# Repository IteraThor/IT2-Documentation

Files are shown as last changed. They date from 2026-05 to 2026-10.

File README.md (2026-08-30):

# IT2 - Autodarts Scoring System Manual



> 🌍 **This manual is available in other languages:** [Deutsch](README.de.md) | [Nederlands](README.nl.md)  
> 🛠️ **Optional Upgrade:** Looking for the mounting plate? [View the IT2 Baseplate Manual](BASEPLATE.md)
> ---
> *Note: Since I'm managing this project on my own, I use AI to help with the repetitive parts of the documentation - mostly for managing hyperlinks and fine-tuning the wording. I'm currently focused on getting all the technical content out there so you can start building as soon as possible. I'll be doing a full proofread and "ironing out" the phrasing later, but if you spot anything confusing in the meantime, please let me know on Discord!*

Welcome to the official manual for the IT2 Autodarts Scoring System. This guide will walk you through the assembly process.

> 📥 **Download Files:** [IT2 System on Makerworld](https://makerworld.com/en/models/1334165)

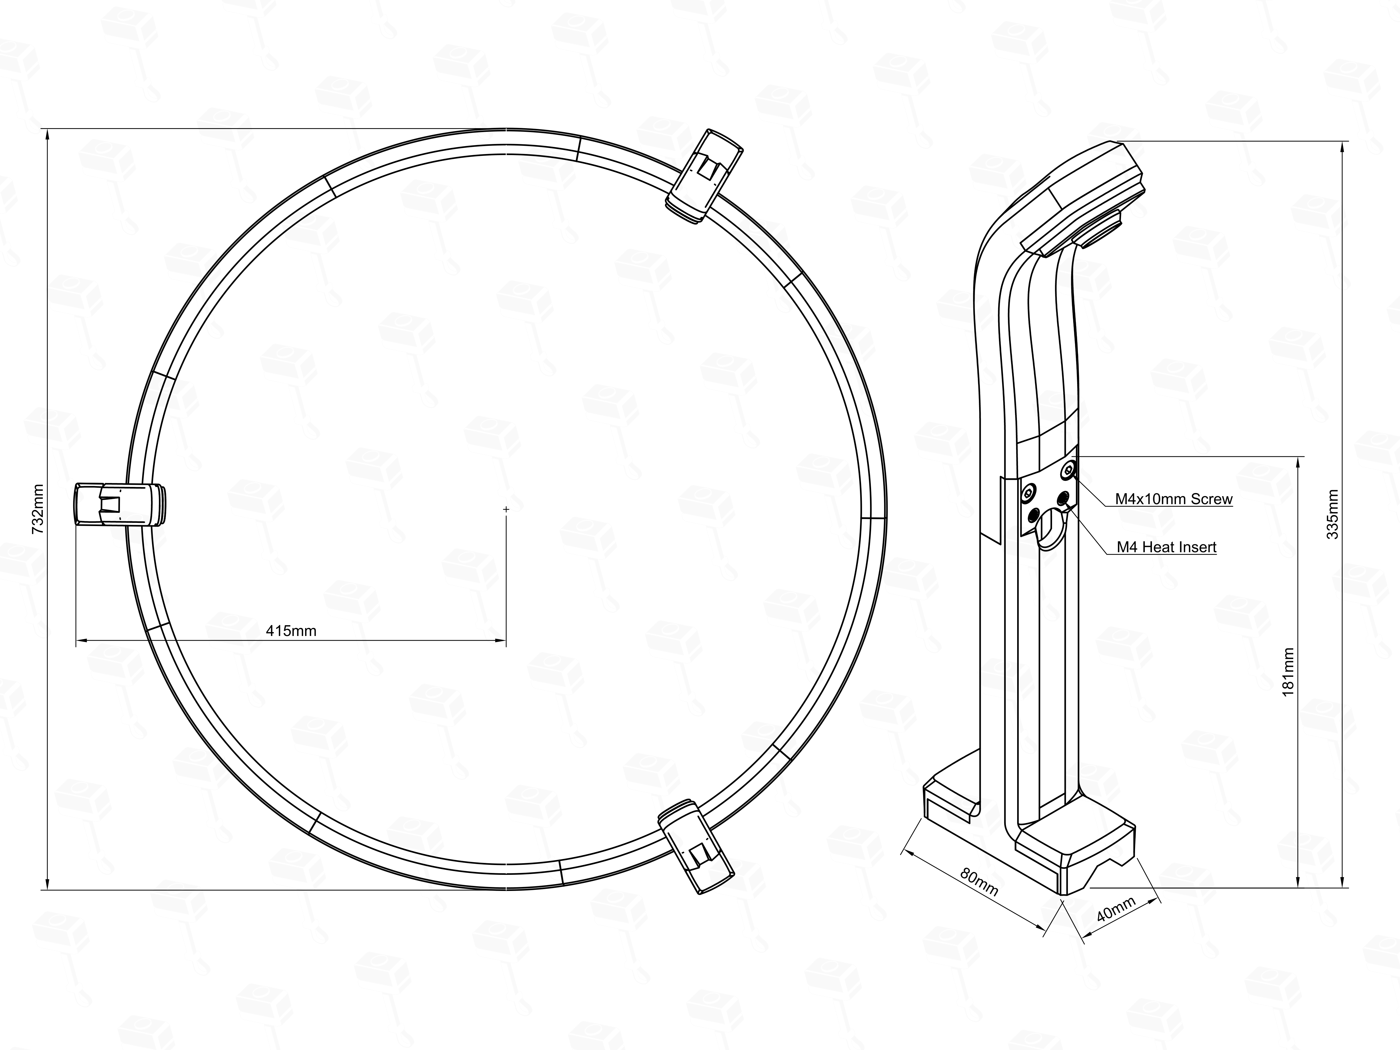
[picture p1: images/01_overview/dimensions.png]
dimensions


---
## Table of Contents
1. [General Overview](#1-general-overview)
2. [What You'll Need](#2-what-youll-need)
    * [2.1 Core Hardware (Required)](#21-core-hardware-required)
    * [2.2 Required Tools](#22-required-tools)
3. [General Assembly: Camera Arms](#3-general-assembly-camera-arms)
    * [3.1 Step 1: Camera Preparation & Resizing](#31-step-1-camera-preparation--resizing)
    * [3.2 Step 2: Heat Inserts Preparation](#32-step-2-heat-inserts-preparation)
    * [3.3 Step 3: Camera Installation & Closing](#33-step-3-camera-installation--closing)
4. [Build Options: Choose Your Path](#4-build-options-choose-your-path)
    * [4.1 Option 1: Winmau Plasma Light Ring](#41-option-1-winmau-plasma-light-ring)
    * [4.2 Option 2: IT2 DIY Light Ring](#42-option-2-it2-diy-light-ring)
    * [4.3 Option 3: Target Corona Light Ring](#43-option-3-target-corona-light-ring)
    * [4.4 Option 4: IT2 DIY Low Ceiling Light Ring](#44-option-4-it2-diy-low-ceiling-light-ring)
5. [Pre-Installation: Camera Positioning](#5-pre-installation-camera-positioning)
6. [Final Step: Installation & Wall Mounting](#6-final-step-installation--wall-mounting)
    * [6.1 Mounting Instructions: Direct Wall Mounting (Option A)](#61-mounting-instructions-direct-wall-mounting-option-a)
    * [6.2 Mounting Instructions: Baseplate Mounting (Option B)](#62-mounting-instructions-baseplate-mounting-option-b)
7. [Pro Tips & Troubleshooting](#7-pro-tips--troubleshooting)
    * [7.1 Assembly Best Practices](#71-assembly-best-practices)
    * [7.2 Hiding Winmau Plasma Power Cable](#72-hiding-winmau-plasma-power-cable)
    * [7.3 Hiding Target Corona Power Cable](#73-hiding-target-corona-power-cable)
8. [Recommended Electronics](#8-recommended-electronics)
9. [FAQ](#9-faq)
10. [Licensing & Community Support](#10-licensing--community-support)

---

## 1. General Overview

### Key Features
*   **Sleek & Slim Design** - The slimmest 3D-printed LED Light Ring as of 2026.
*   **Hidden Cable Management** - Internal routing for a clean look. Fits Corona or Plasma power barrels without any modifications.
*   **No-Support Printing** - Designed for zero supports, minimizing material waste and print time.
*   **Universal Compatibility** - Native support for Winmau Plasma, Target Corona, and IT2 DIY Rings.
*   **Flexible Assembly** - Choose between the **Heat Insert** version or the **Self-Tapping** version (no heat inserts required).
*   **Minimalist Hardware** - Built using only 12x M4x10mm screws and 6x M2x6mm screws.

---

## 2. What You'll Need

> **Note:** Many of the product links below are affiliate links. If you use them to make a purchase, I may receive a small commission at no additional cost to you, which helps support the development of this project.

> 🖨️ **3D Printing:** If you are not using the Makerworld .3mf profiles, please refer to the **[Universal Printing Guide](PRINTING.md)** for recommended settings and materials.

### 2.1 Core Hardware (Required) 

| Part Name | Type | Qty | Link | Comment |
| --- | --- | --- | ---- | --- |
| Cylindrical Screws | M4x10mm (ISO4762/DIN912) | 12  | [Aliexpress](https://s.click.aliexpress.com/e/_c4WUfT79)<br>[Amazon.de](https://amzn.to/49r8kCE) | Required for most of the assembly. |
| Cylindrical Screws | M2x6mm (ISO4762/DIN912)  | 6 | [Aliexpress](https://s.click.aliexpress.com/e/_c4WUfT79)<br>[Amazon.de](https://amzn.to/4u4l5du) | Camera screws. |
| M4 Heat Inserts ⚠️ | 6.3mm OD (max 9mm long) | 12  | [Aliexpress](https://s.click.aliexpress.com/e/_c3iaYfkD)<br>[Amazon.de](https://amzn.to/4wZr2uZ) | 6mm OD also fits. <br><br>⚠️ **Only for the Heat Insert version.** |

> 💡 **Looking for more?** [View Recommendations for Electronics & Accessories](#8-recommended-electronics)

### 2.2 Required Tools

| Tool | Link | Purpose |
| --- | --- | --- |
| Hex Key Set | [Aliexpress](https://s.click.aliexpress.com/e/_c3OuwTrf)<br>[Amazon.de](https://amzn.to/4nWmdhU) | For M4 and M2 cylindrical screws. |
| Pliers / Side Cutters | [Aliexpress](https://s.click.aliexpress.com/e/_c4NYxuoH)<br>[Amazon.de](https://amzn.to/3PBMeql) | Required for resizing the camera frames from 38x38 to 32x32. |
| Soldering Iron | [Aliexpress](https://s.click.aliexpress.com/e/_c3Jtjkzn)<br>[Amazon.de](https://amzn.to/3PBMeql) | Required for melting M4 heat inserts (Heat Insert version only). |

---

## 3. General Assembly: Camera Arms

Before building your specific version (DIY, Winmau Plasma, or Target Corona), you need to prepare and assemble the three camera arms. This process is identical for all versions.

### 3.1 Step 1: Camera Preparation & Resizing
> Some cameras come with a 38x38mm mounting frame. To make them fit, you need to **break the outer frame** to downsize them to **32x32mm**.

*   Carefully break off the perforated edges using a pair of pliers.

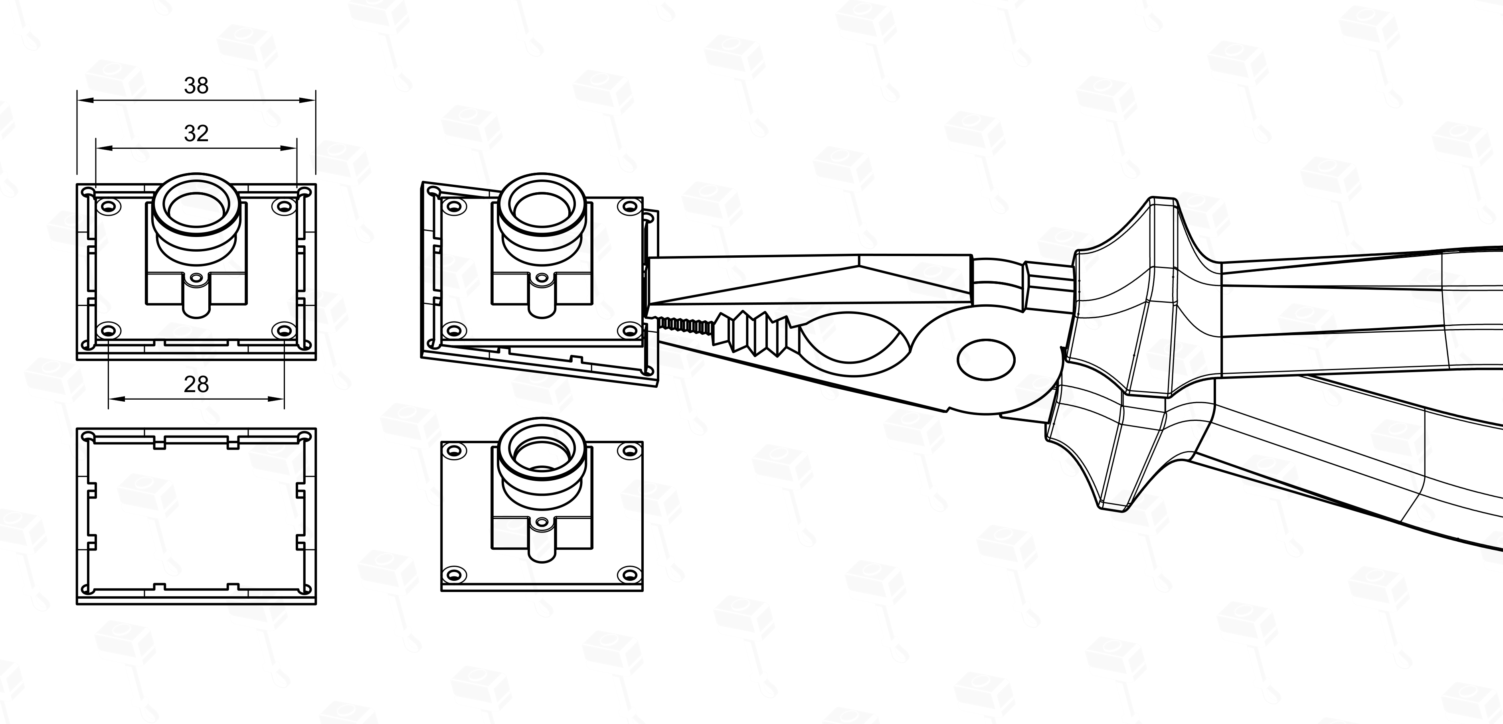
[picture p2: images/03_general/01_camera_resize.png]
camera-resize


### 3.2 Step 2: Heat Inserts Preparation
> **Self-Tapping Version:** If you printed this version, you can skip this step.

Melt the **M4 inserts** into the holes of the camera arms and heads using a soldering iron, as shown in the image below.

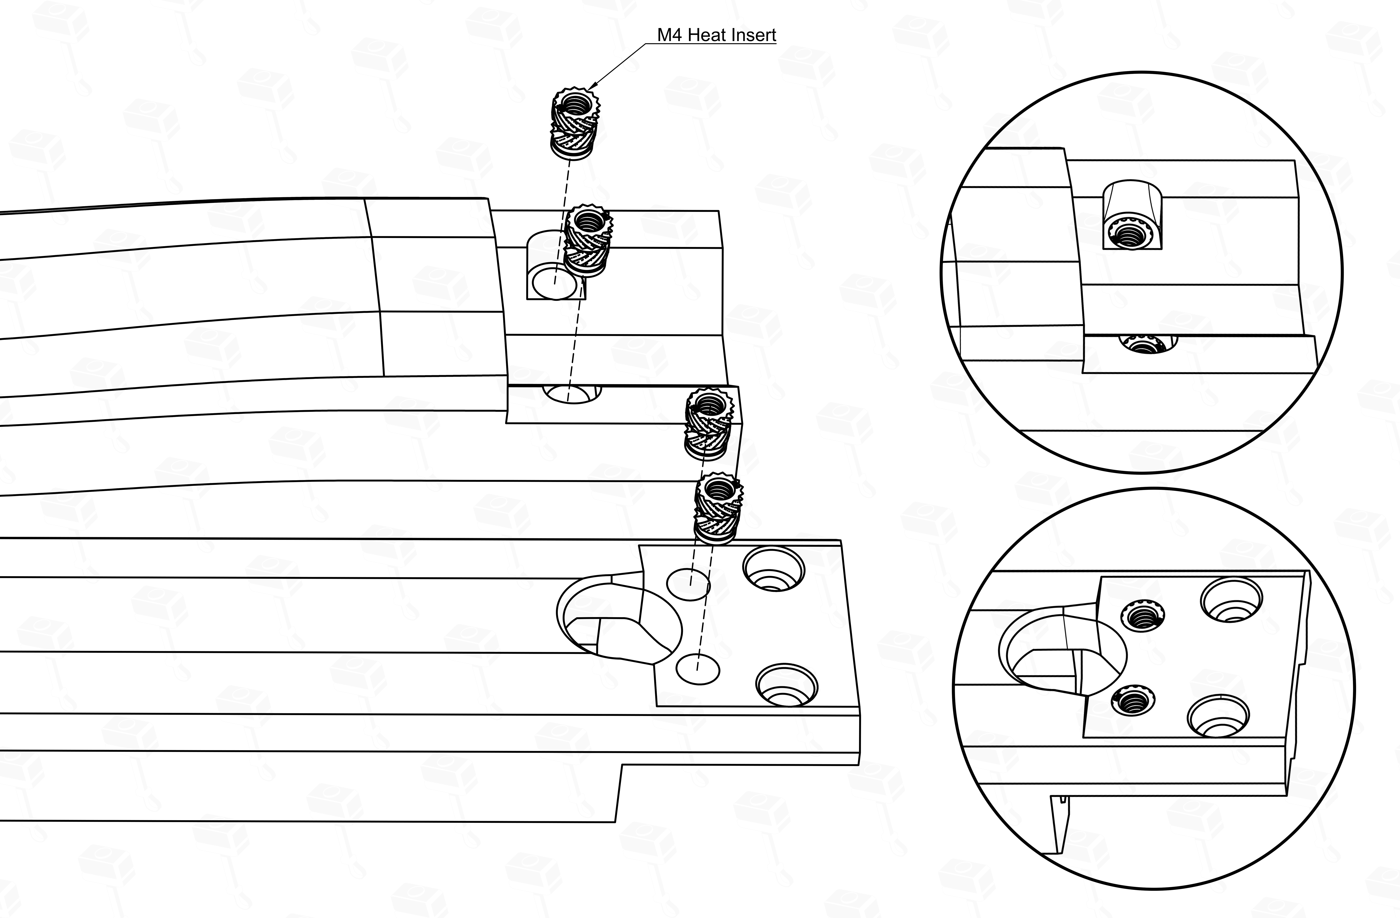
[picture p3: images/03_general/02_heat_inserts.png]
heat_inserts


### 3.3 Step 3: Camera Installation & Closing
**1. Head & Arm Assembly**  
Connect the camera head and the arm using two **M4 screws**. After that, pull the USB cable through the internal channel of the housing and connect it to the 4-pin connector of the camera.

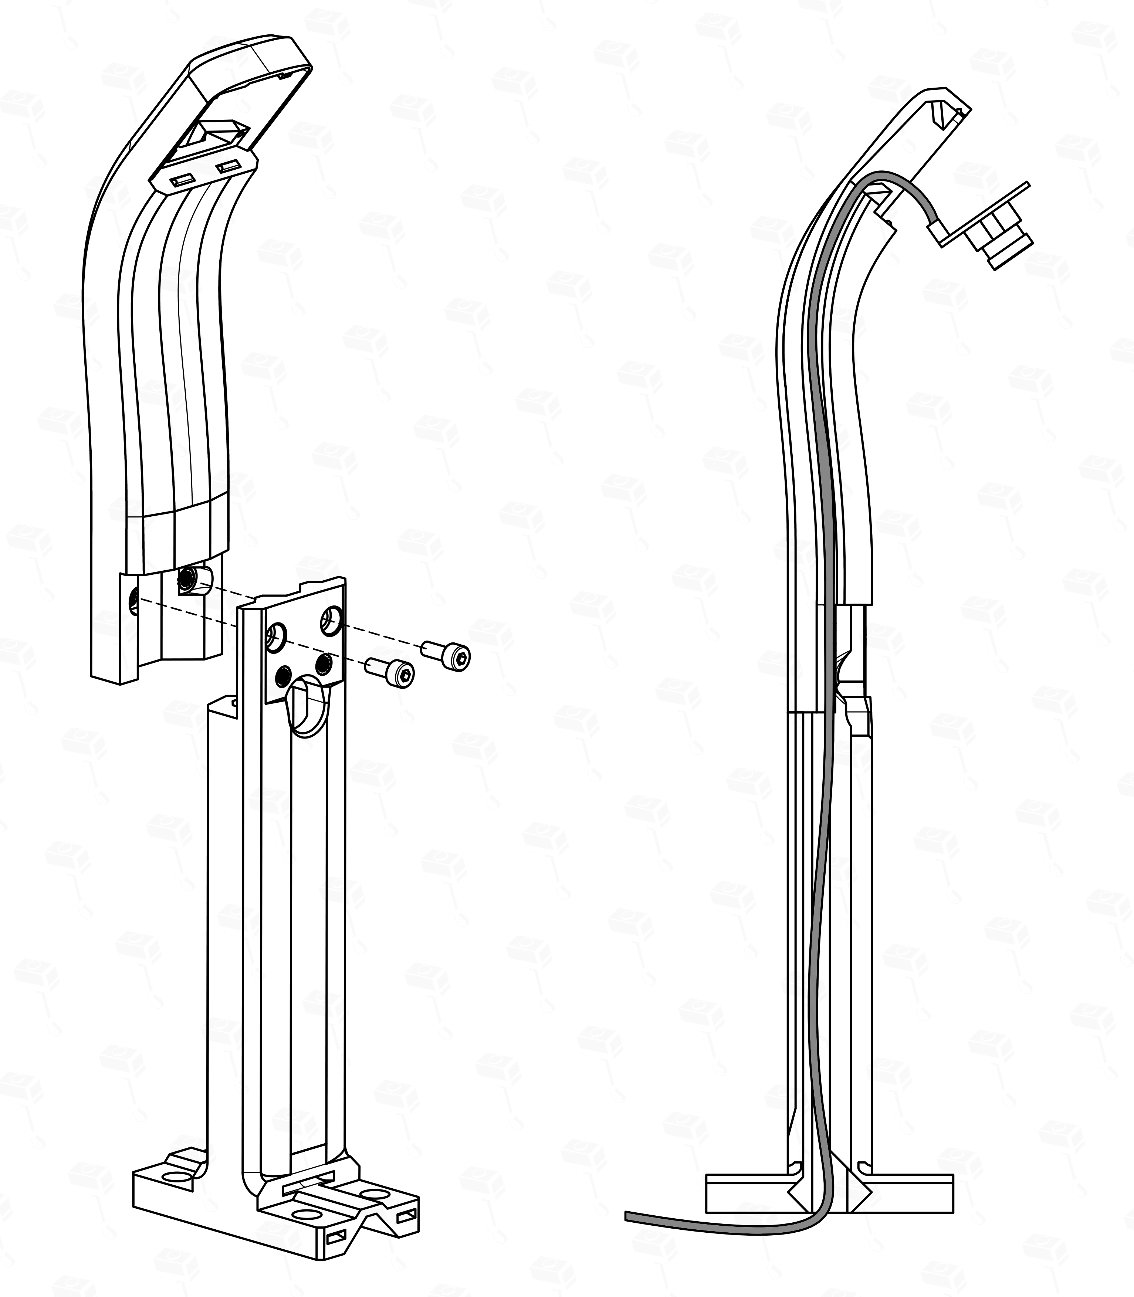
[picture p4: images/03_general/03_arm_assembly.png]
arm_assembly


**2. Camera Installation**  
Secure the camera PCB with two **M2 screws**. 

> **Note:** These holes are self-tapping. Using only two screws is recommended and intentional.

**3. Lens Hood & Closing**  
Twist the lens hood clockwise into the camera cover (twist-lock) and then click the cover onto the head.
> **Tip:** Choose between the two different lens hood designs included in the print profile.

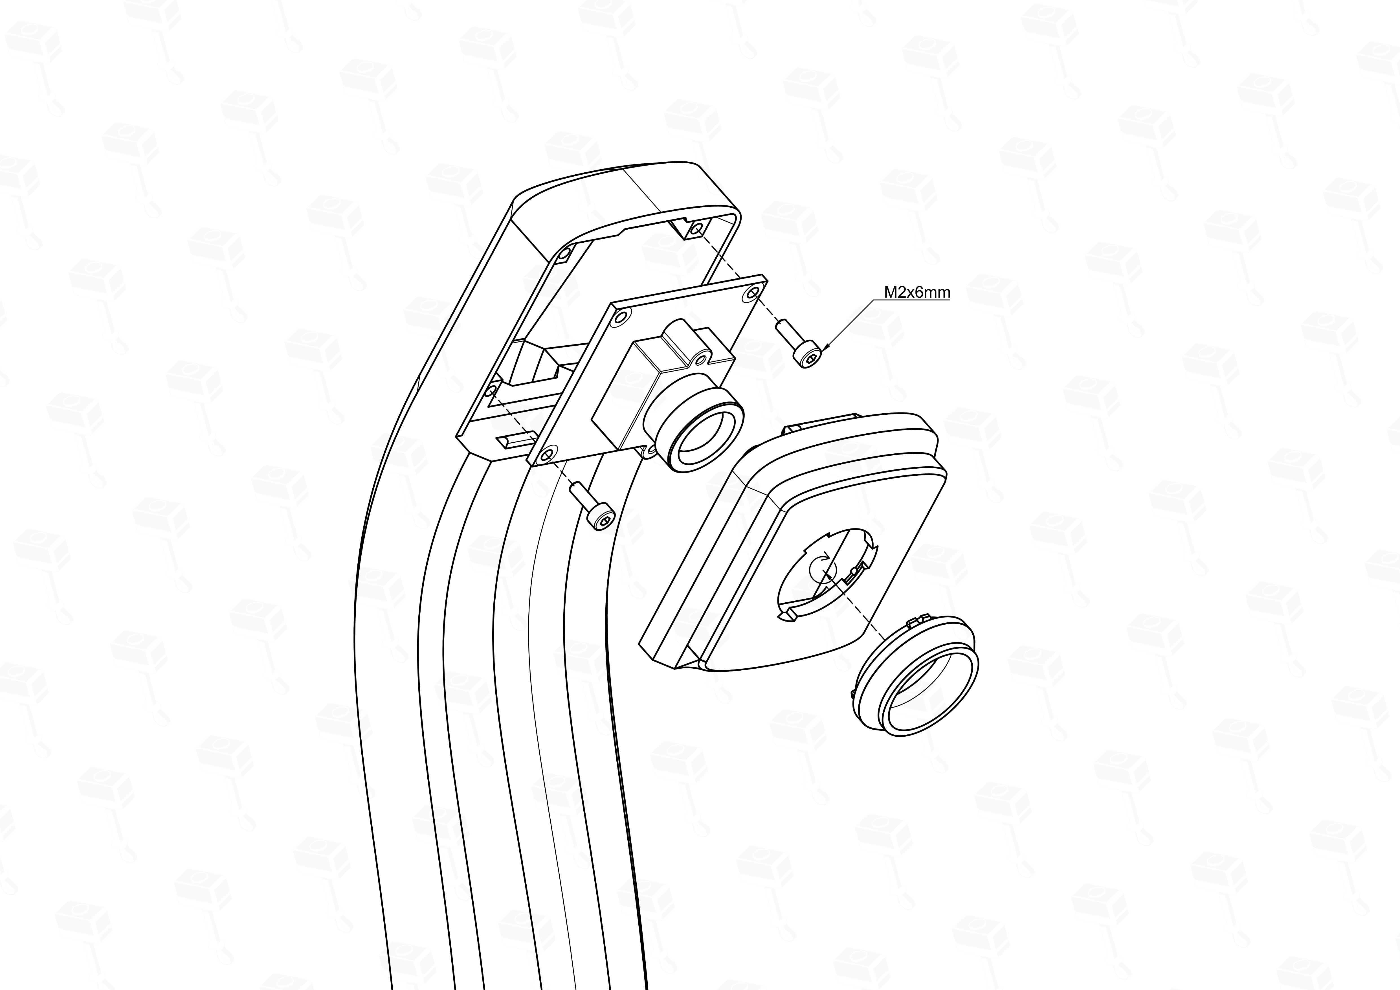
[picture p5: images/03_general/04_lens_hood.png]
lens_hood


**Final Result of Phase 1**  
Upon completing these steps, you should have three fully assembled camera arms ready for installation.

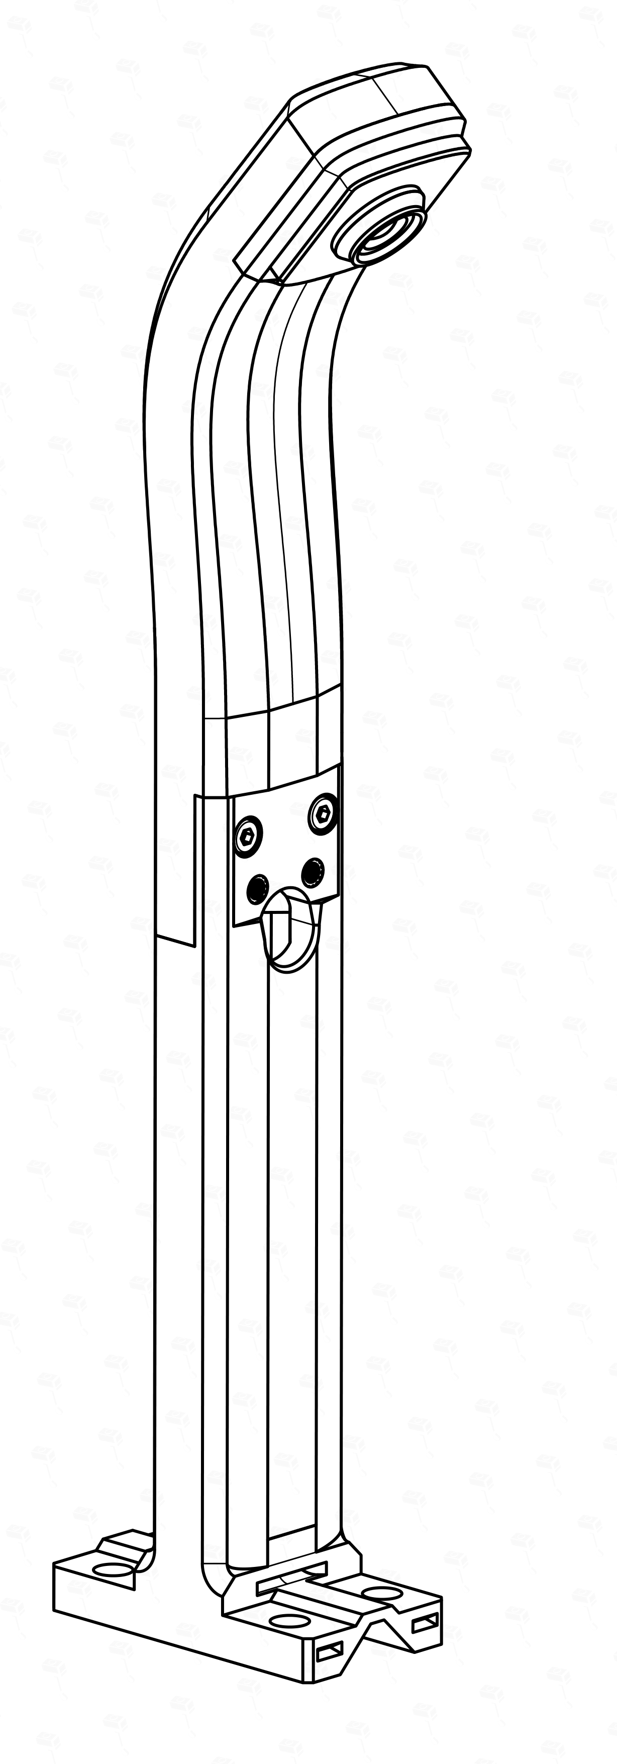
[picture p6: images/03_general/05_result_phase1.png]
fully assembled camera arms
[](images/03_general/05_result_phase1.png)

---

## 4. Build Options: Choose Your Path

After your camera arms are prepared, choose the build guide that matches your setup.

### 4.1 Option 1: Winmau Plasma Light Ring

> **Pro Tip:** You have the option to route the Winmau Plasma power cable through the internal channels of the IT2 system for an even cleaner look. This requires a few extra steps - see [Section 7.2: Hiding Winmau Plasma Power Cable](#72-hiding-winmau-plasma-power-cable) for details.

**Step 1: Mounting the Arms**  
Attach the three [prepared camera arms](#3-general-assembly-camera-arms) to the designated positions on the Winmau Plasma ring. The IT2 arms are designed to fit perfectly onto the Plasma's profile. Use M4 screws to secure them.  

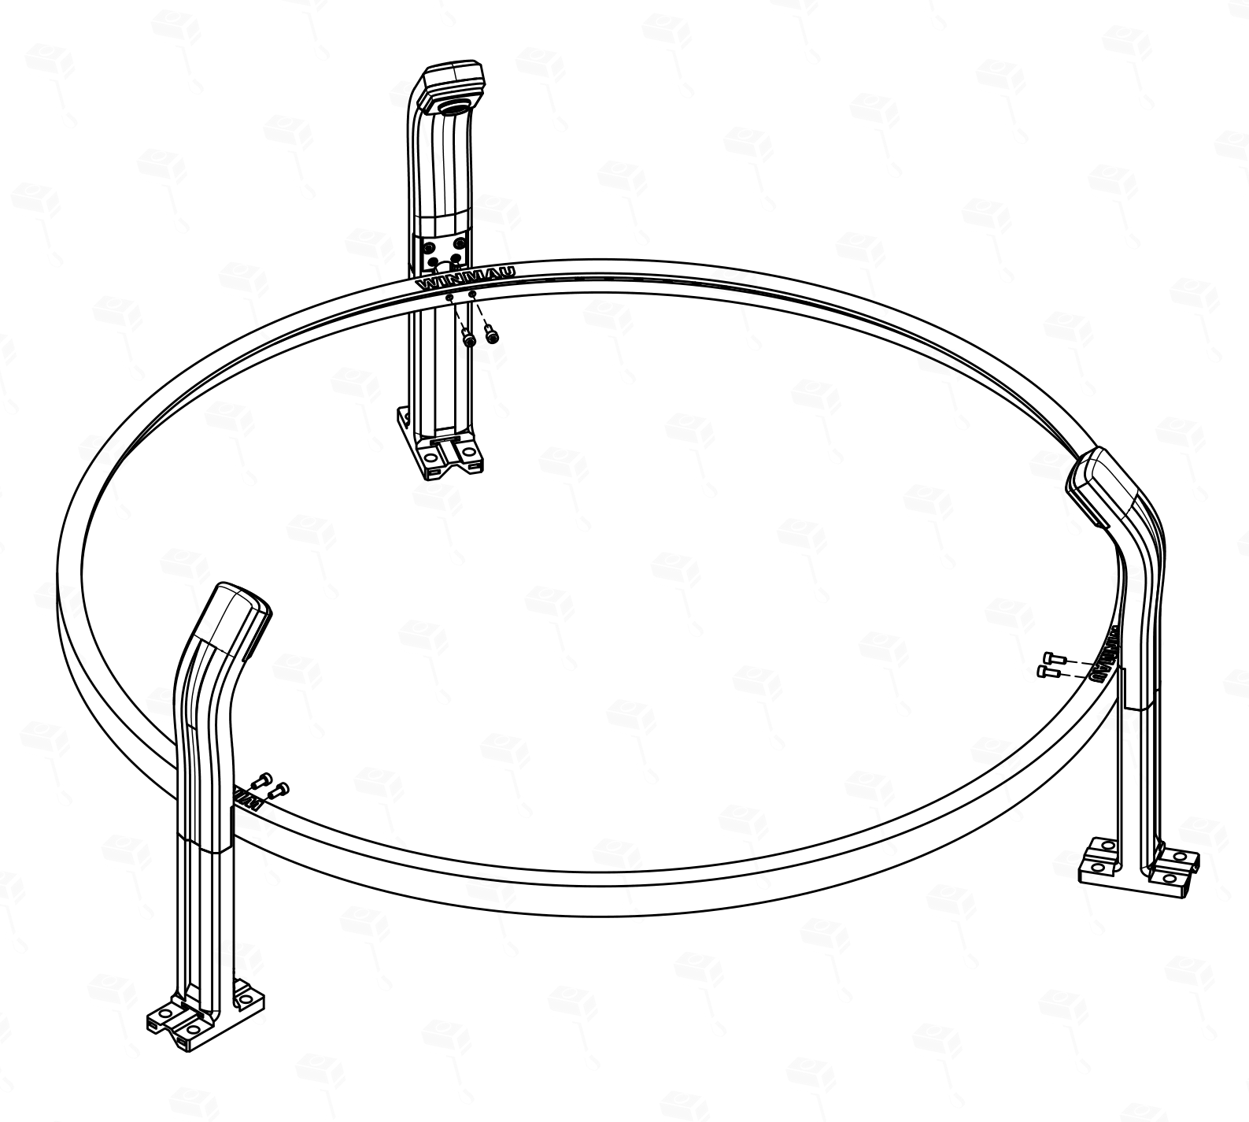
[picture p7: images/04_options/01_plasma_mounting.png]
plasma_mounting


[Back to Table of Contents](#table-of-contents) | **Next Step: [5. Pre-Installation: Camera Positioning](#5-pre-installation-camera-positioning)**

---

### 4.2 Option 2: IT2 DIY Light Ring

**Step 1: Ring Assembly**  
Connect the 3D-printed segments of the IT2 DIY Light Ring. Ensure a tight connection to maintain stability.

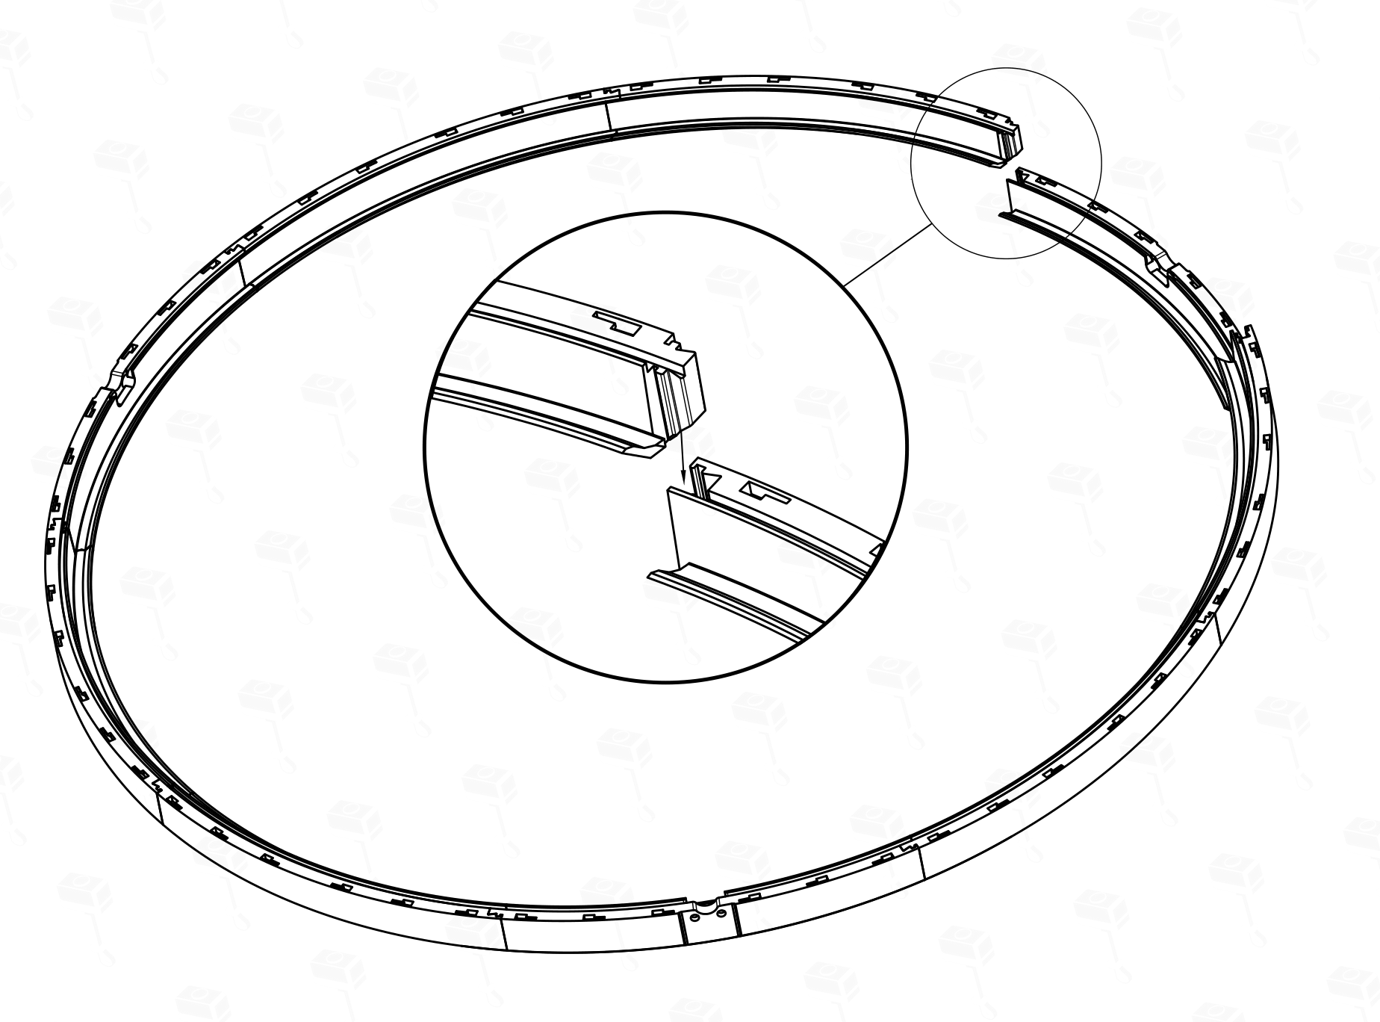
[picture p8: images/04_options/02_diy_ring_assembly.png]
ring_dovetail


**Step 2: LED Installation**  
Install the **LED strip** in the designated channel of the ring. Start from the bottom to allow for clean power cable routing.

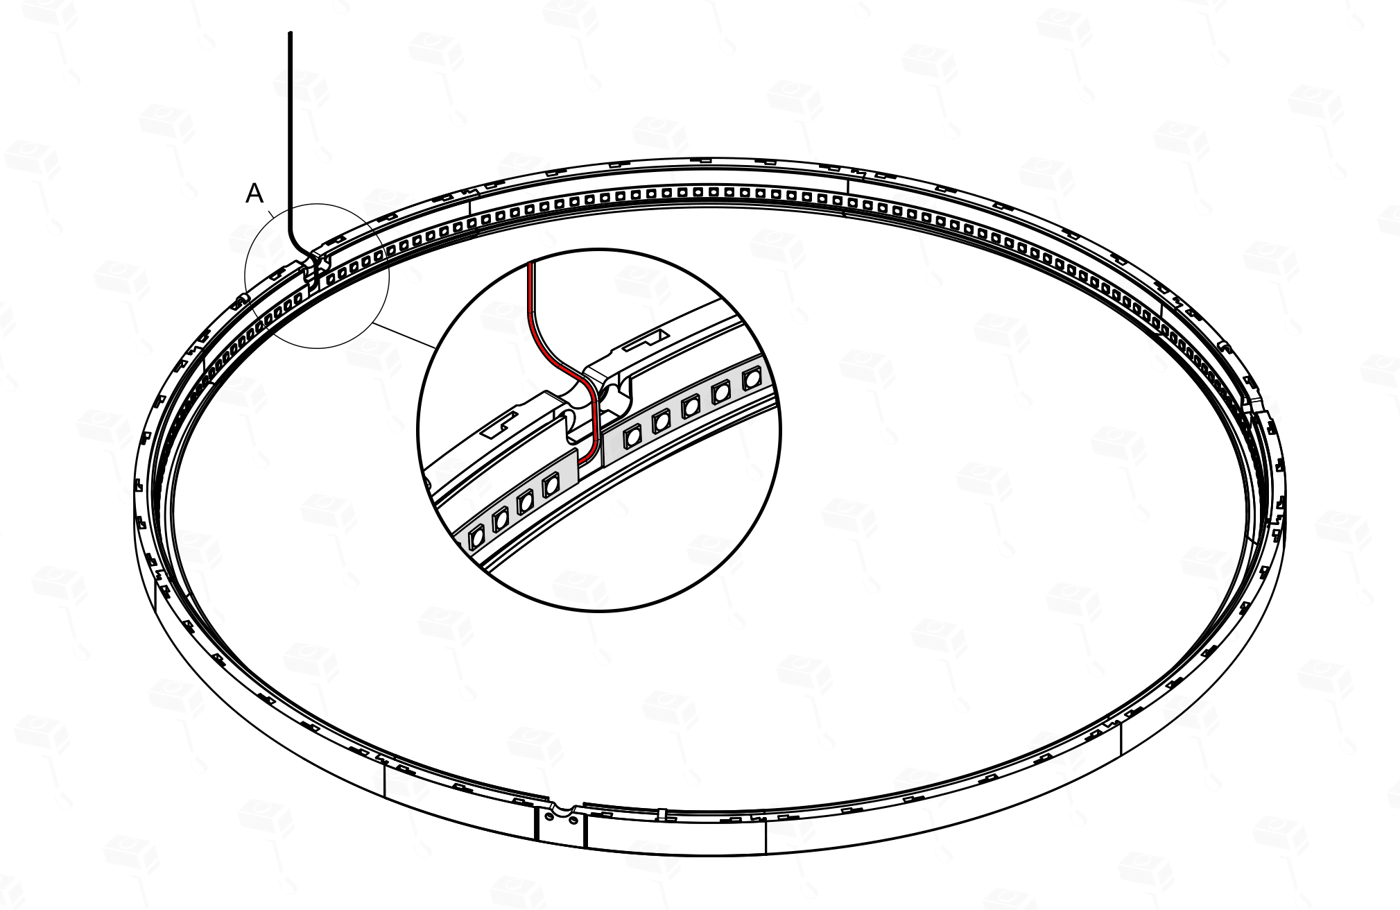
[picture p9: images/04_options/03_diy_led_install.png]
led_install


**Step 3: Attaching the Arms**  
Secure the camera arms to the integrated mounting points on the DIY ring using M4 screws.

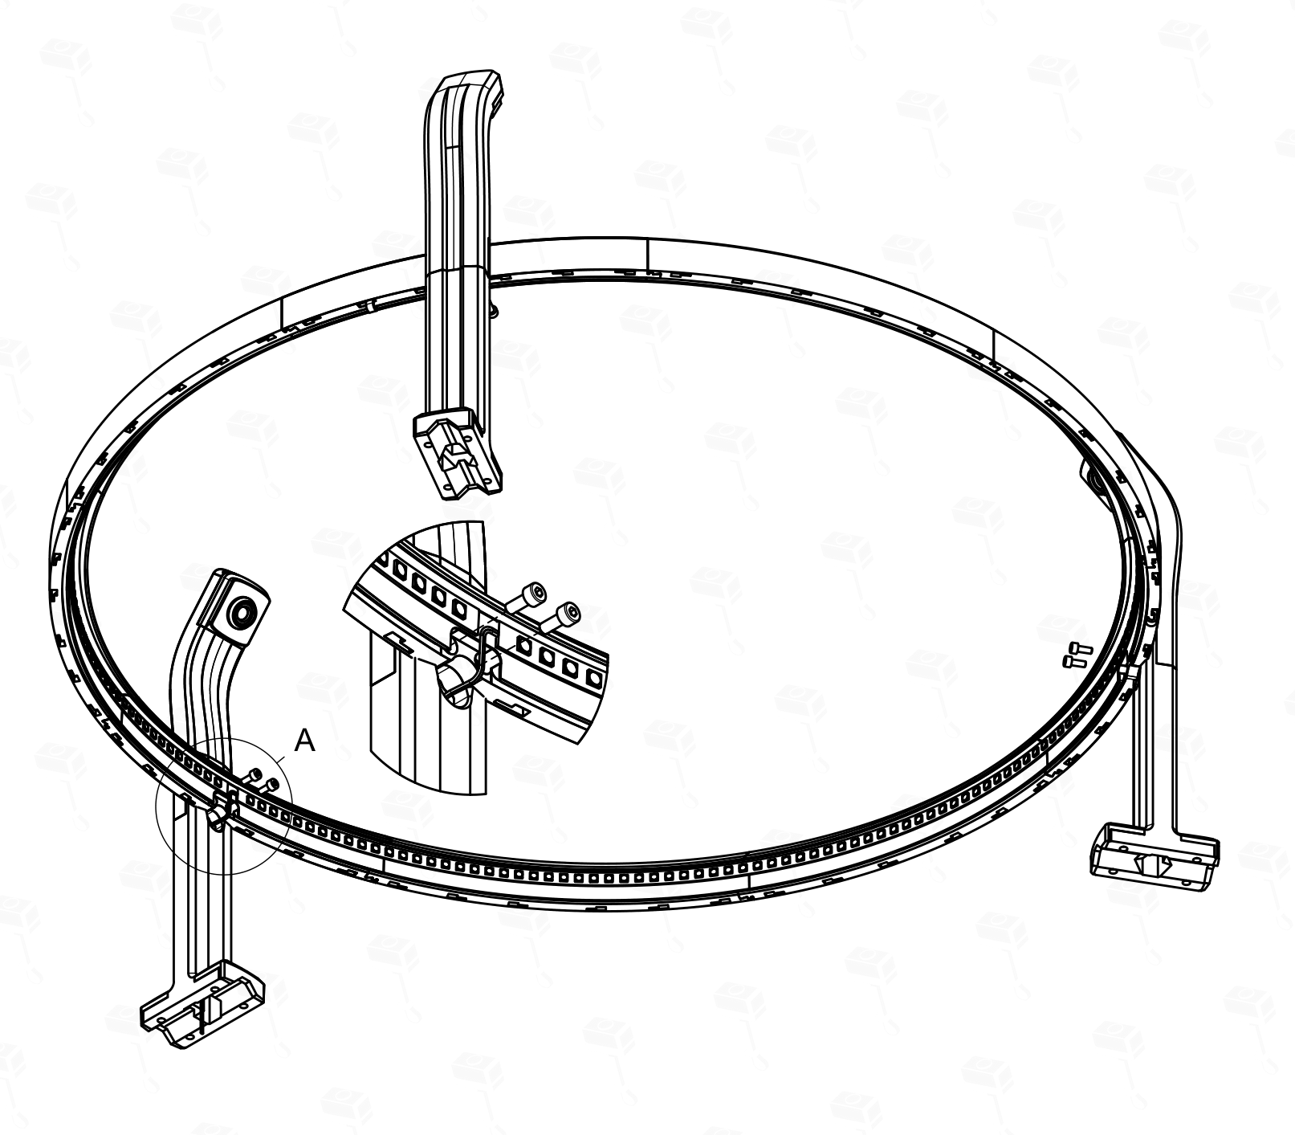
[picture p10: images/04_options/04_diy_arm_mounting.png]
arm_mounting


[Back to Table of Contents](#table-of-contents) | **Next Step: [5. Pre-Installation: Camera Positioning](#5-pre-installation-camera-positioning)**

---

### 4.3 Option 3: Target Corona Light Ring

**Step 1: Adapter Preparation**  
Install the **bottom part of the IT2 Corona Adapter** onto the three [prepared camera arms](#3-general-assembly-camera-arms) using M4 screws. 

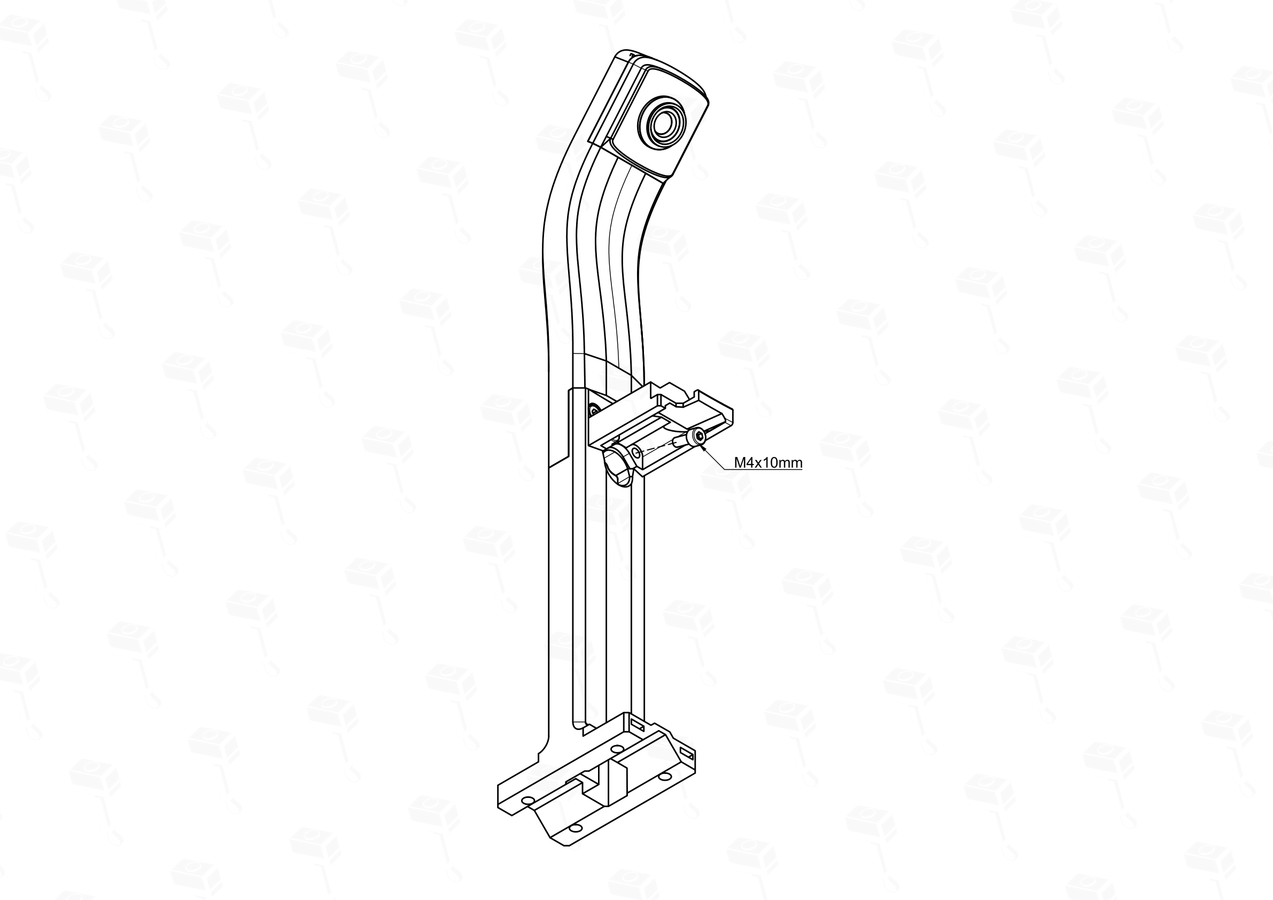
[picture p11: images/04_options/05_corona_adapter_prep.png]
corona_adapter_prep


**Step 2: Mounting & Alignment**  
Place the Target Corona ring into the recesses of the installed bottom adapter parts. 

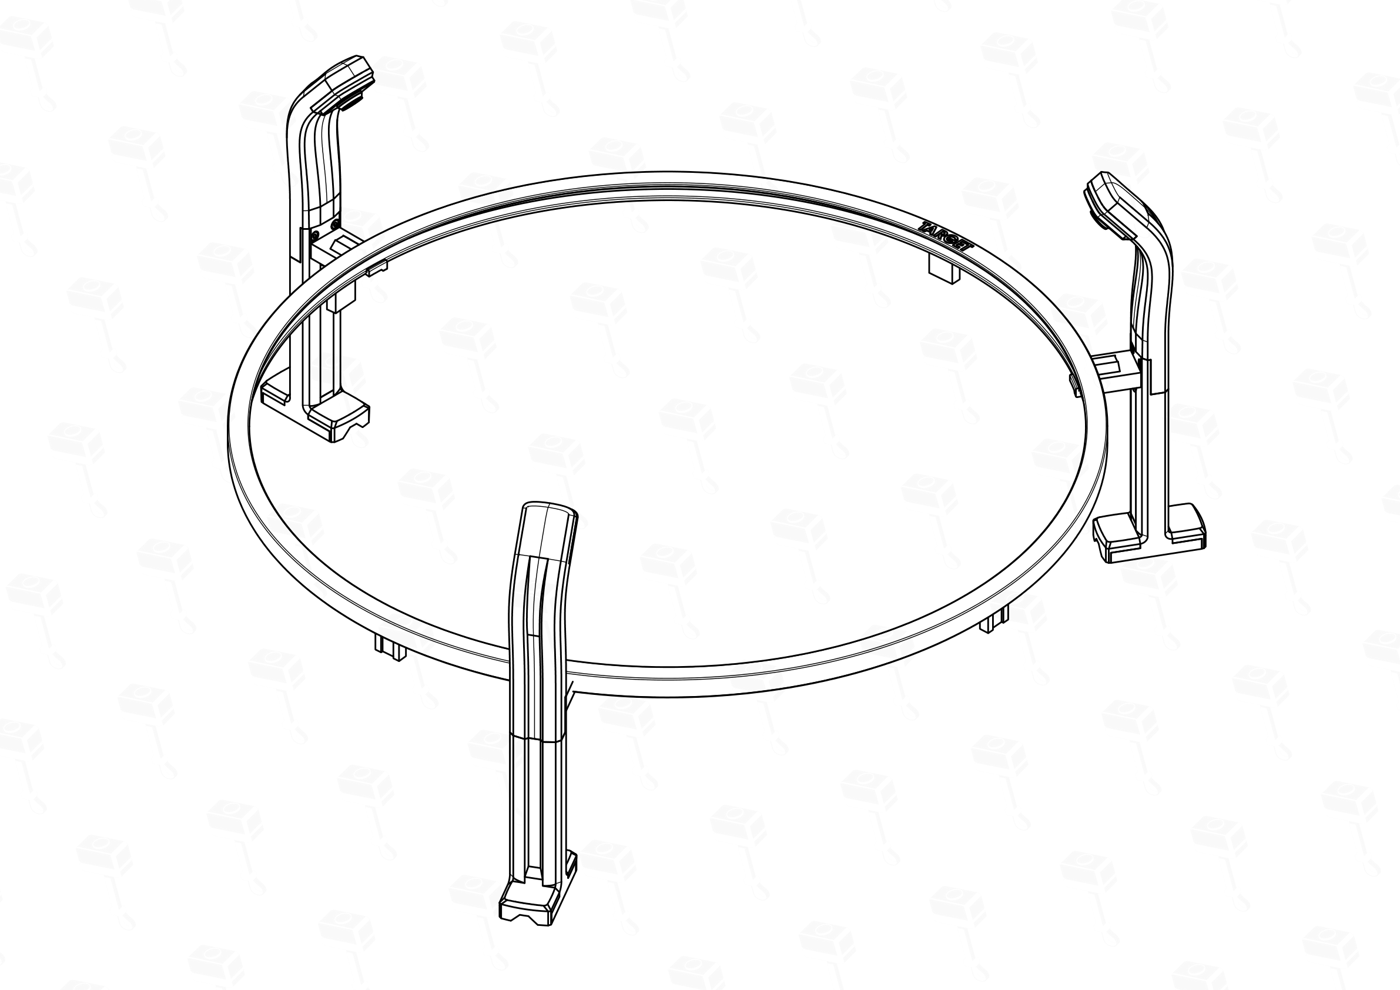
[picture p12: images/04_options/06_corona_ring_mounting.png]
corona_ring_mounting


Then, hook the **upper part of the adapter** into the ring and snap it into place. 

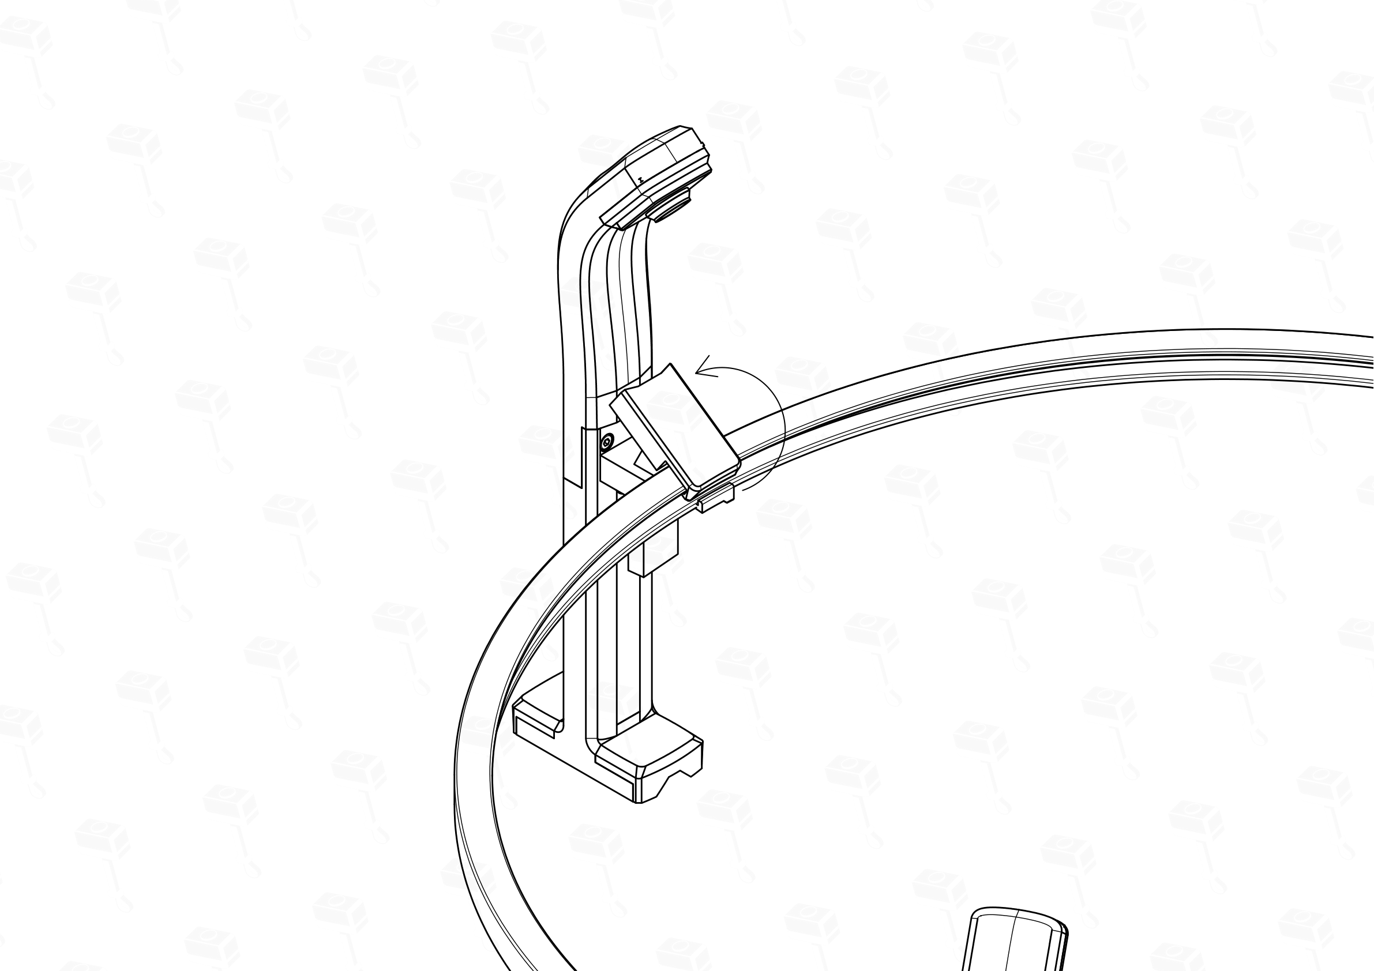
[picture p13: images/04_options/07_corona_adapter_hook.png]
corona_adapter_hook


> **Tip:** Try to position the adapters at an approximate **120-degree offset** while snapping them on. This will minimize the amount of fine-tuning needed later.

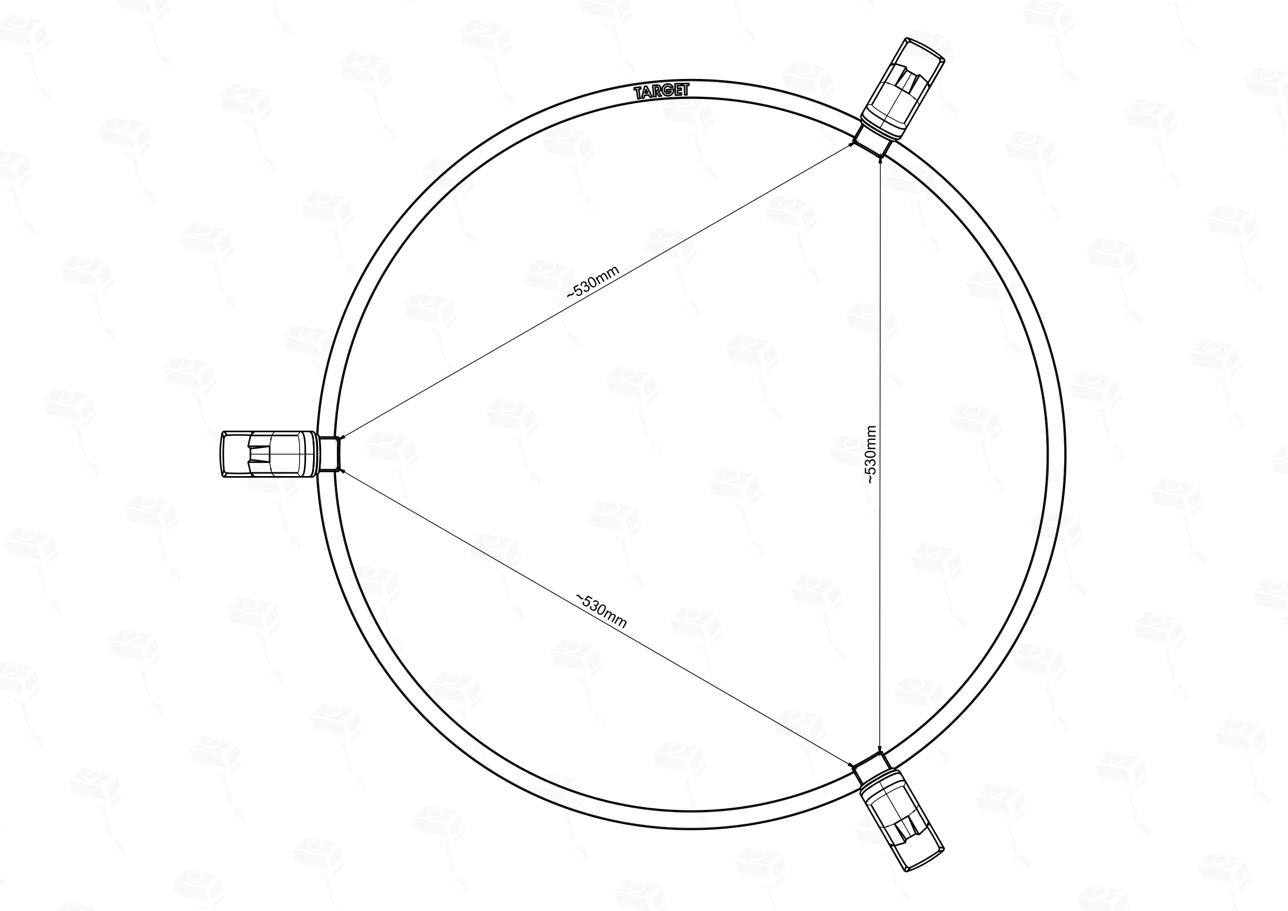
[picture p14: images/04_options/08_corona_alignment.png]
corona_alignment


> **Pro Tip:** You have the option to route the Target Corona power cable through the internal channels of the IT2 system for an even cleaner look. This requires a few extra steps - see [Section 7.3: Hiding Target Corona Power Cable](#73-hiding-target-corona-power-cable) for details.

[Back to Table of Contents](#table-of-contents) | **Next Step: [5. Pre-Installation: Camera Positioning](#5-pre-installation-camera-positioning)**

---

### 4.4 Option 4: IT2 DIY Low Ceiling Light Ring

> This version was specifically developed for rooms with low ceiling height. It requires a ceiling height of at least **2.00m**.

**Assembly Instructions**  
The assembly logic for this version is identical to the standard DIY ring. Please follow the detailed **[step-by-step instructions in Section 4.2](#42-option-2-it2-diy-light-ring)**.

> 💡 **Tip:** Unlike the standard ring, the Low Ceiling version consists of **6 different segment types**. Please note that all three segments that mount to the cameras are different from the standard version - two of them are mirrored and shorter to accommodate the ceiling clearance. Before connecting the dovetails, lay out all pieces on the floor in the correct order to avoid sequence errors. Once connected, the pieces are often very difficult to pull apart without risking damage.

**Final Result**  
After assembly, your Low Ceiling Light Ring should look as follows:

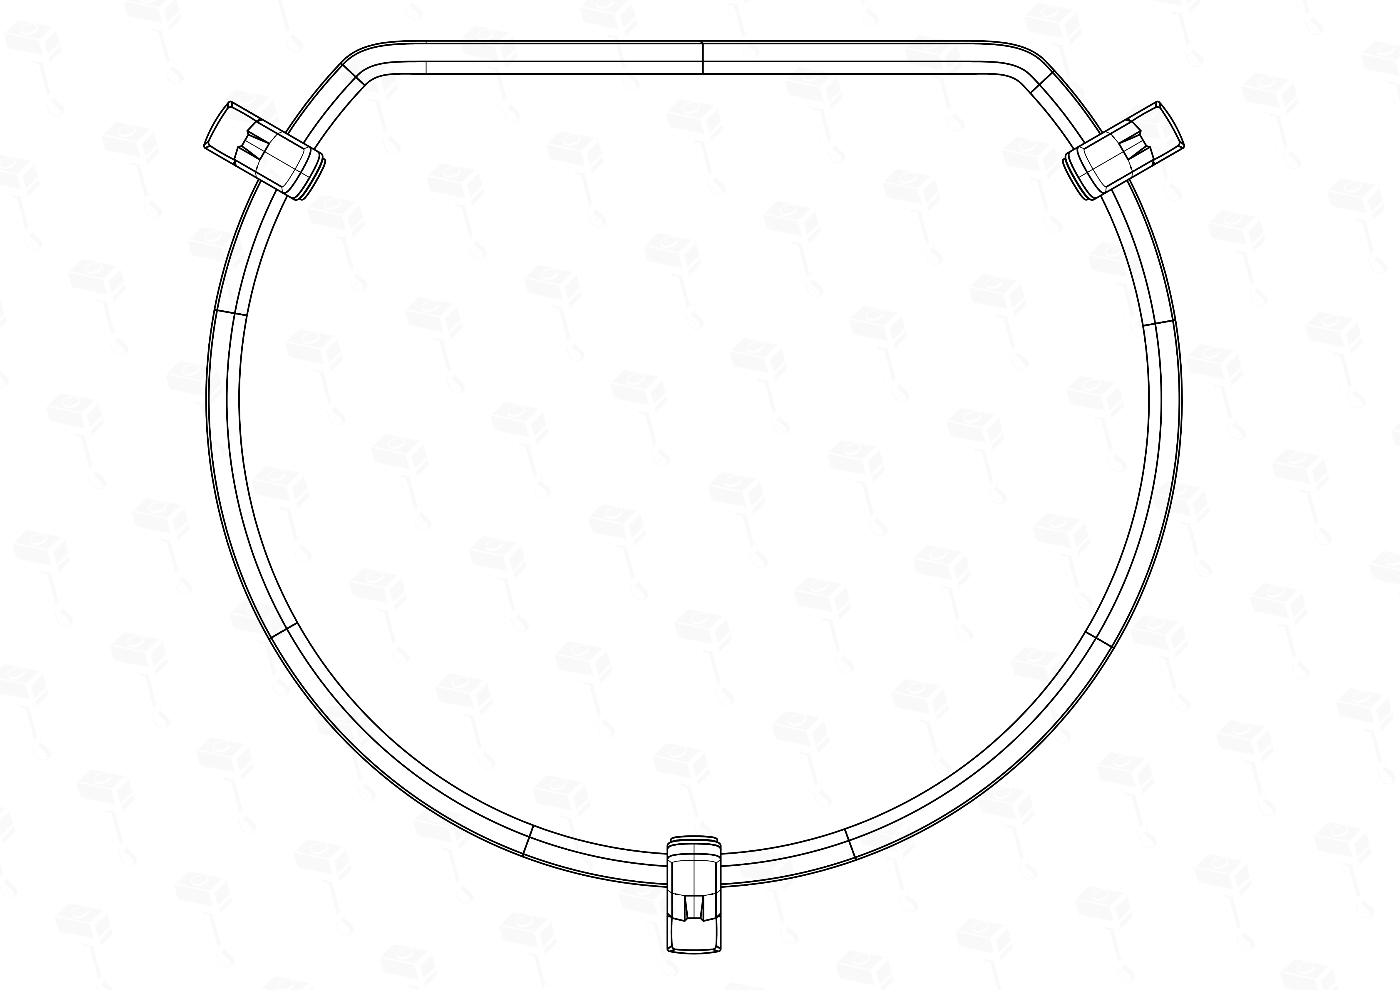
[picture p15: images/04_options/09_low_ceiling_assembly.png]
low_ceiling_assembly


[Back to Table of Contents](#table-of-contents) | **Next Step: [5. Pre-Installation: Camera Positioning](#5-pre-installation-camera-positioning)**

---

## 5. Pre-Installation: Camera Positioning

Before mounting your system, you need to decide on the orientation of your camera arms. 

> **Camera Positioning**  
> Align camera arms with the **11** or **6** segments for optimal recognition ([Autodarts Guidelines](https://autodarts.diy/getting-started/camera-positioning/)).  
> **Note:** The **Low Ceiling** or **portable stand** version uses the **3** segment instead.

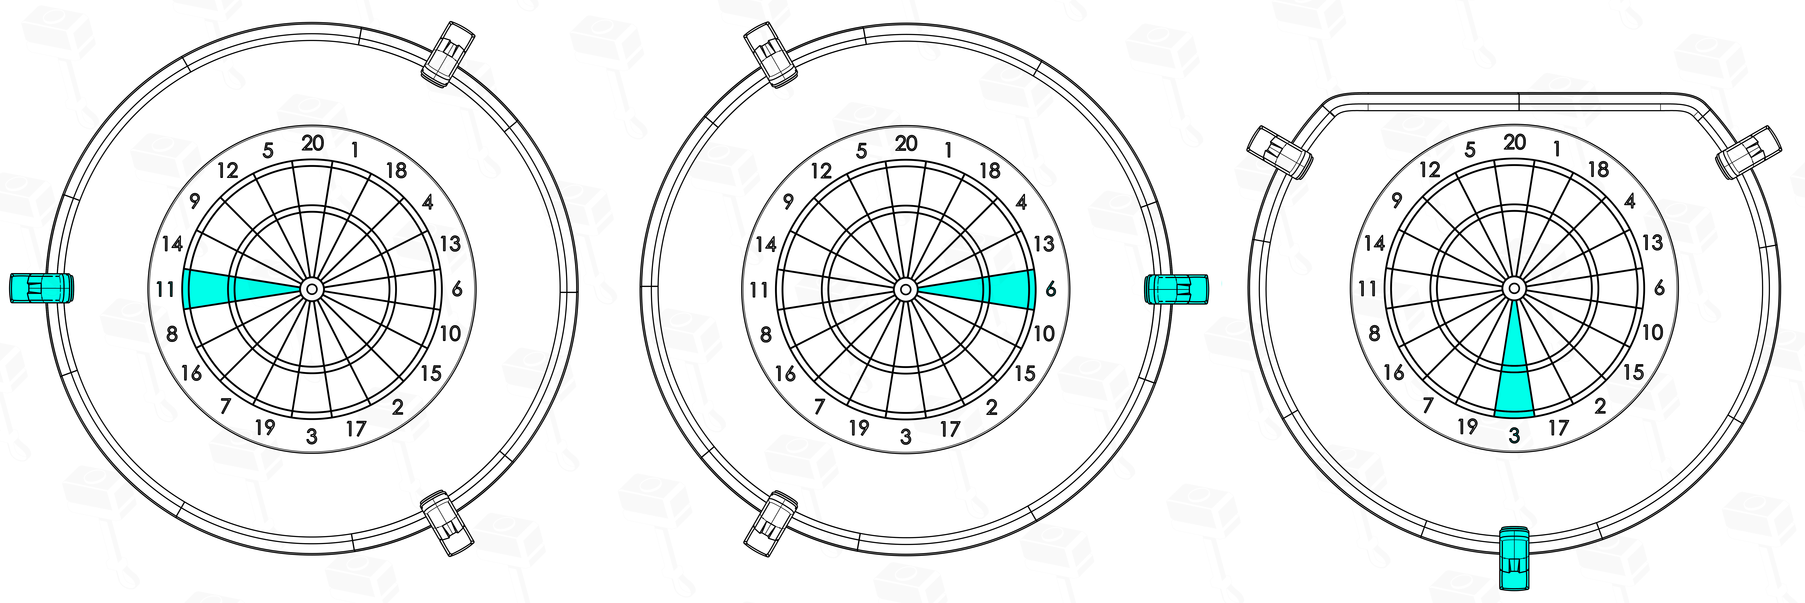
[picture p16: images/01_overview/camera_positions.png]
camera_positions


---

## 6. Final Step: Installation & Wall Mounting

The IT2 system offers two main installation paths, depending on your requirements for aesthetics, mounting effort, and wall protection.

### Option A: Direct Mounting
In this configuration, the IT2 system is mounted directly to the wall. This requires drilling **6 holes** for the arms and **2 additional holes** for the dartboard hanger (if not already present).
*   **Pros:** Fewer parts to assemble; minimal footprint; system sits flush against the wall.
*   **Cons:** Requires more drill points; leg positions must be determined manually via measurements, drawing circles, or using a drill template.

### Option B: IT2 Baseplate
The **[IT2 Baseplate](BASEPLATE.md)** is an optional unit that simplifies the installation process and offers additional features like sound dampening and native stand compatibility.

For detailed instructions on how to install and align the baseplate, please refer to the **[Baseplate Assembly & Installation Guide](BASEPLATE.md)**.

---

### 6.1 Mounting Instructions: Direct Wall Mounting (Option A)
There are two ways to ensure your system is perfectly aligned when mounting directly to the wall:

#### Method 1: Using the IT2 Drill Template (Recommended)
This is the easiest and most precise way to position your mounting holes.
1. Align the center of the template with your marked bullseye height (1.73m).
2. Level the template.
3. Mark the drill positions through the designated points on the template.
    > 💡 **Tip:** To minimize drilling while maintaining perfect stability, I recommend using only **two diagonal holes** per arm (e.g., top-left and bottom-right) instead of all four.

> 💡 **Tip:** If you want to change the orientation of the camera arms (e.g., placing the main arm on the left instead of the right), simply flip the template upside down. You can then use a spirit level on the bottom edge to align it perfectly.

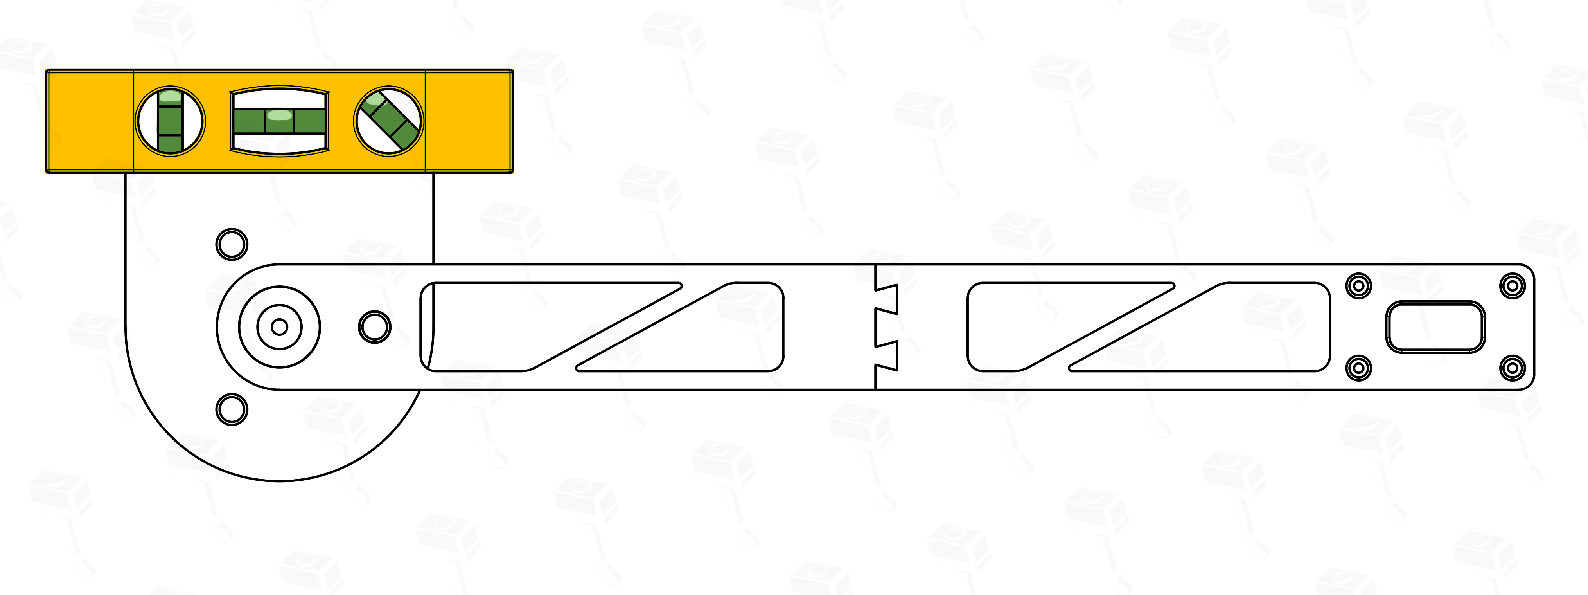
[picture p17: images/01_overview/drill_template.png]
drill_template


#### Method 2: Manual Marking & Drawing
If you prefer to mark the positions yourself without the 3D-printed template, follow the measurements shown in the technical drawing below. This ensures the correct 120-degree offset and distance from the bullseye.

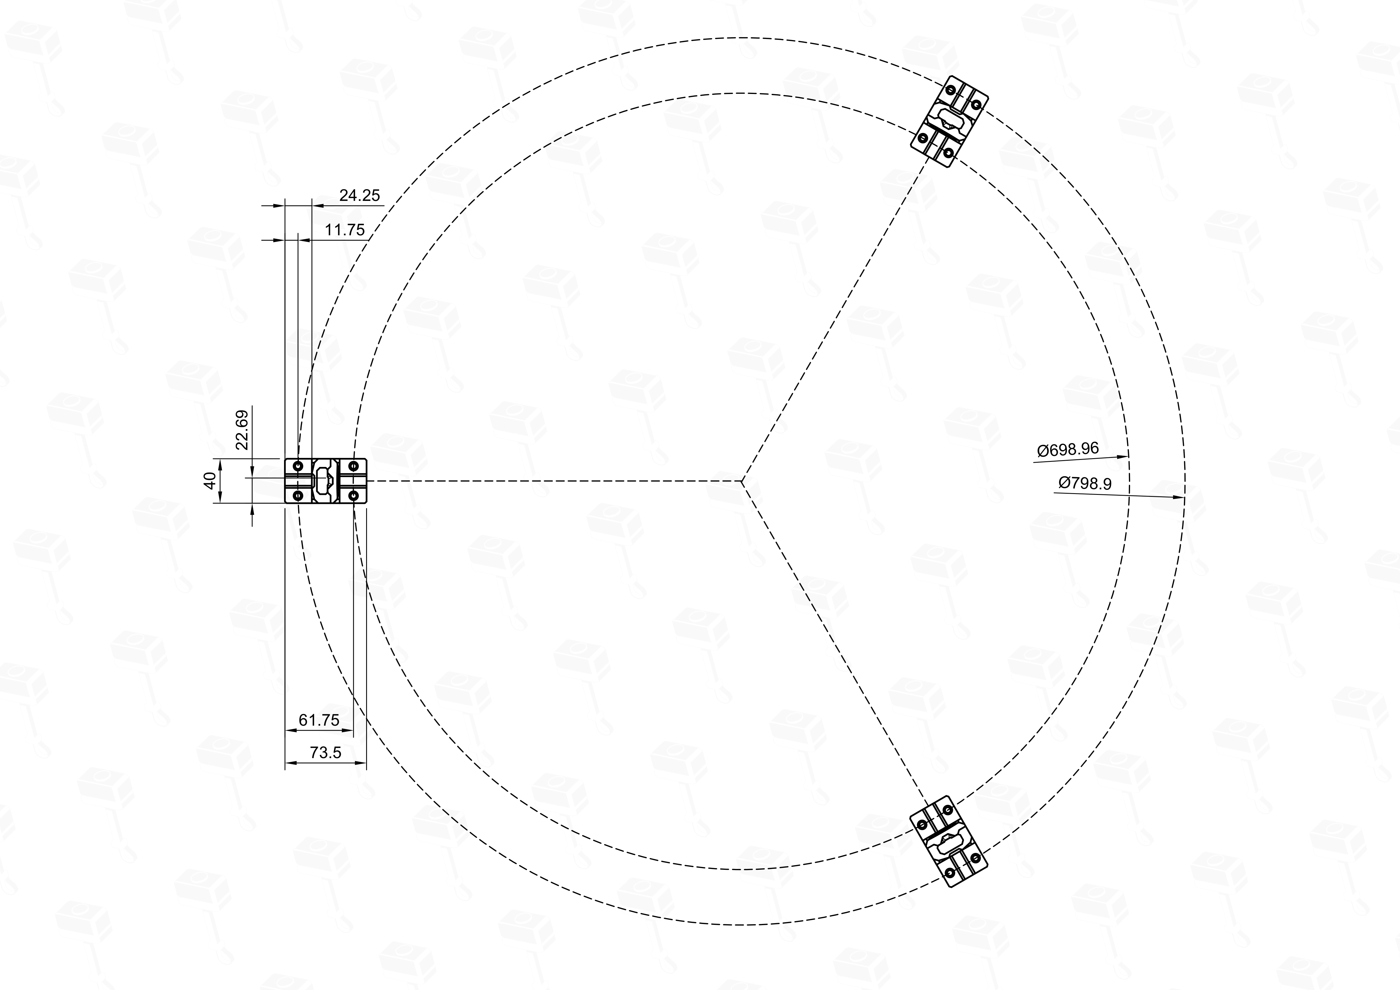
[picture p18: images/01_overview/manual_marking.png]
manual_marking


---

### 6.2 Mounting Instructions: Baseplate Mounting (Option B)
Please refer to the **[IT2 Baseplate Manual](BASEPLATE.md)** for detailed, step-by-step instructions on wall mounting and alignment.

[Back to Table of Contents](#table-of-contents)

---

## 7. Pro Tips & Troubleshooting

To ensure the best possible experience with your IT2 system, follow these pro tips.

### 7.1 Assembly Best Practices
When tightening screws, ensure they are only **"finger-tight"**.
*   Avoid over-tightening as this can stress the heat inserts.
*   **Self-Tapping Version:** Be extra careful with the self-tapping version. The plastic threads can easily strip, which is **irreversible** if too much force is applied.

### 7.2 Hiding Winmau Plasma Power Cable
**Step 1:** ...
**Step 2:** ...
*(Instructions coming soon)*

### 7.3 Hiding Target Corona Power Cable
**Step 1:** ...
**Step 2:** ...
*(Instructions coming soon)*

[Back to Table of Contents](#table-of-contents)

---

## 8. Recommended Electronics

| Part Name | Type | Link | Comment |
| --- | --- | ---- | --- |
| Cameras | HBV OV2710 | [Aliexpress](https://s.click.aliexpress.com/e/_c4bziy33) | Best price-to-performance cameras. |
| LED Strip | Auxmer 5000k 12V 9.6W LED Strip | [Aliexpress](https://s.click.aliexpress.com/e/_c3z7FC4l) | My favorite. Best color reproduction. |
| Power Supply | 12V 3A Power Adapter | [Aliexpress](https://s.click.aliexpress.com/e/_c2IYxq1R) | Required for the DIY LED strip. |
| DC Connector | 2.1mm DC Socket | [Aliexpress](https://s.click.aliexpress.com/e/_c3L2uy4H) | To connect the power supply to the LEDs. |
| PC | Dell Wyse 5070 ≥4GB RAM ≥ 16GB Storage | | My favorite. Good price-to-performance ratio. |
| Touchscreen  | Anmite 16" Touchscreen | [Aliexpress](https://s.click.aliexpress.com/e/_c34qKHYZ) | My favorite. Good price-to-performance ratio. |

---

## 9. FAQ

### Q: Which cameras should I choose?
**A:** The clear winner for price-to-performance is the **HBV OV2710**. Investing in more expensive, higher-resolution cameras is unnecessary as Autodarts is resolution-limited. While the **OV9732** is a cheaper alternative, it requires significantly better lighting; therefore, I exclusively recommend the OV2710 for its superior handling of various light conditions.

### Q: Which LED strip should I get?
**A:** Avoid USB light strips. The community favorite for a good, cheap strip is 6000K COB LEDs (12V or 24V). My personal recommendation is the Auxmer 5000K LEDs/m (9.6W, CRI90); in my tests, it even outperformed the Winmau Plasma. If you're on a budget, get a 6000K strip; if you want the best for your eyes and the cameras, get the Auxmer 5000K.

### Q: Should I use a Raspberry Pi or a Mini PC?
**A:** Unless you already own a Raspberry Pi, I recommend buying a refurbished Mini PC. They are often cheaper (starting at €50) and offer better performance and touchscreen support. My personal favorite is the **Dell Wyse 5070** (4GB RAM, 16GB storage), which is widely available refurbished and handles the Autodarts software perfectly.

---

## 10. Licensing & Community Support
IT2 is provided under a custom license. For information regarding commercial use, private sharing, and community support, please refer to the **[LICENSE.md](LICENSE.md)** file.

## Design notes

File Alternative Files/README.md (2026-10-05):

| File | Image  | Description |
| --- | --- | --- |
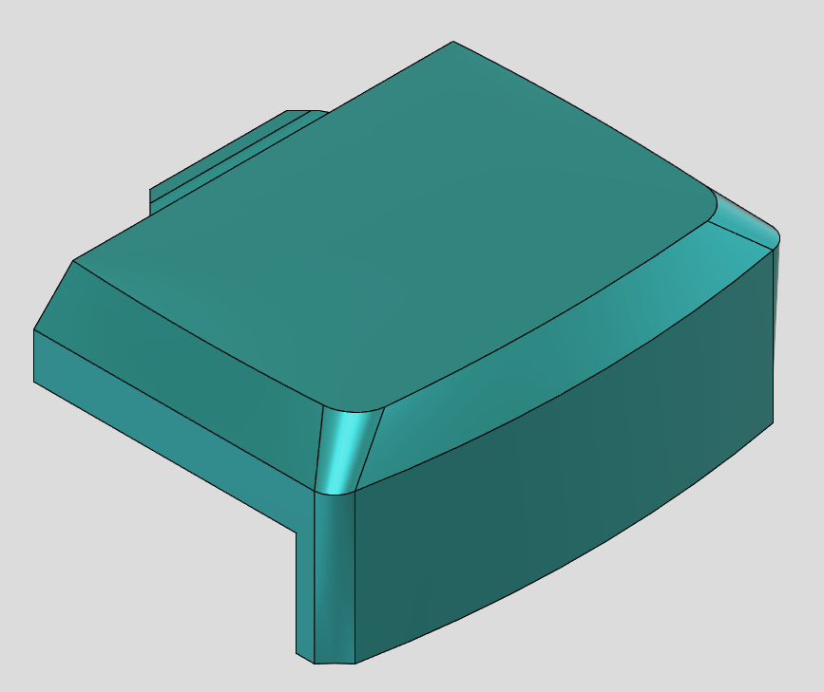
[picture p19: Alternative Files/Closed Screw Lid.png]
Closed Screw Lid
| closed screw lid.stl  |  | closed lid to close ends without cables. |

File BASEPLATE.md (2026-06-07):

# IT2 Baseplate - Installation & Assembly Guide



> 🛠️ **Main Manual:** Looking for the camera system instructions? [View the IT2 System Manual](README.md)
>
> ---
> *Note: Since I'm managing this project on my own, I use AI to help with the repetitive parts of the documentation - mostly for managing hyperlinks and fine-tuning the wording. I'm currently focused on getting all the technical content out there so you can start building as soon as possible. I'll be doing a full proofread and "ironing out" the phrasing later, but if you spot anything confusing in the meantime, please let me know on Discord!*

The **IT2 Baseplate** is a mounting solution for the IT2 Autodarts system. It is designed to simplify installation, protect your walls, and provide advanced features like sound dampening and native compatibility with dartboard stands.

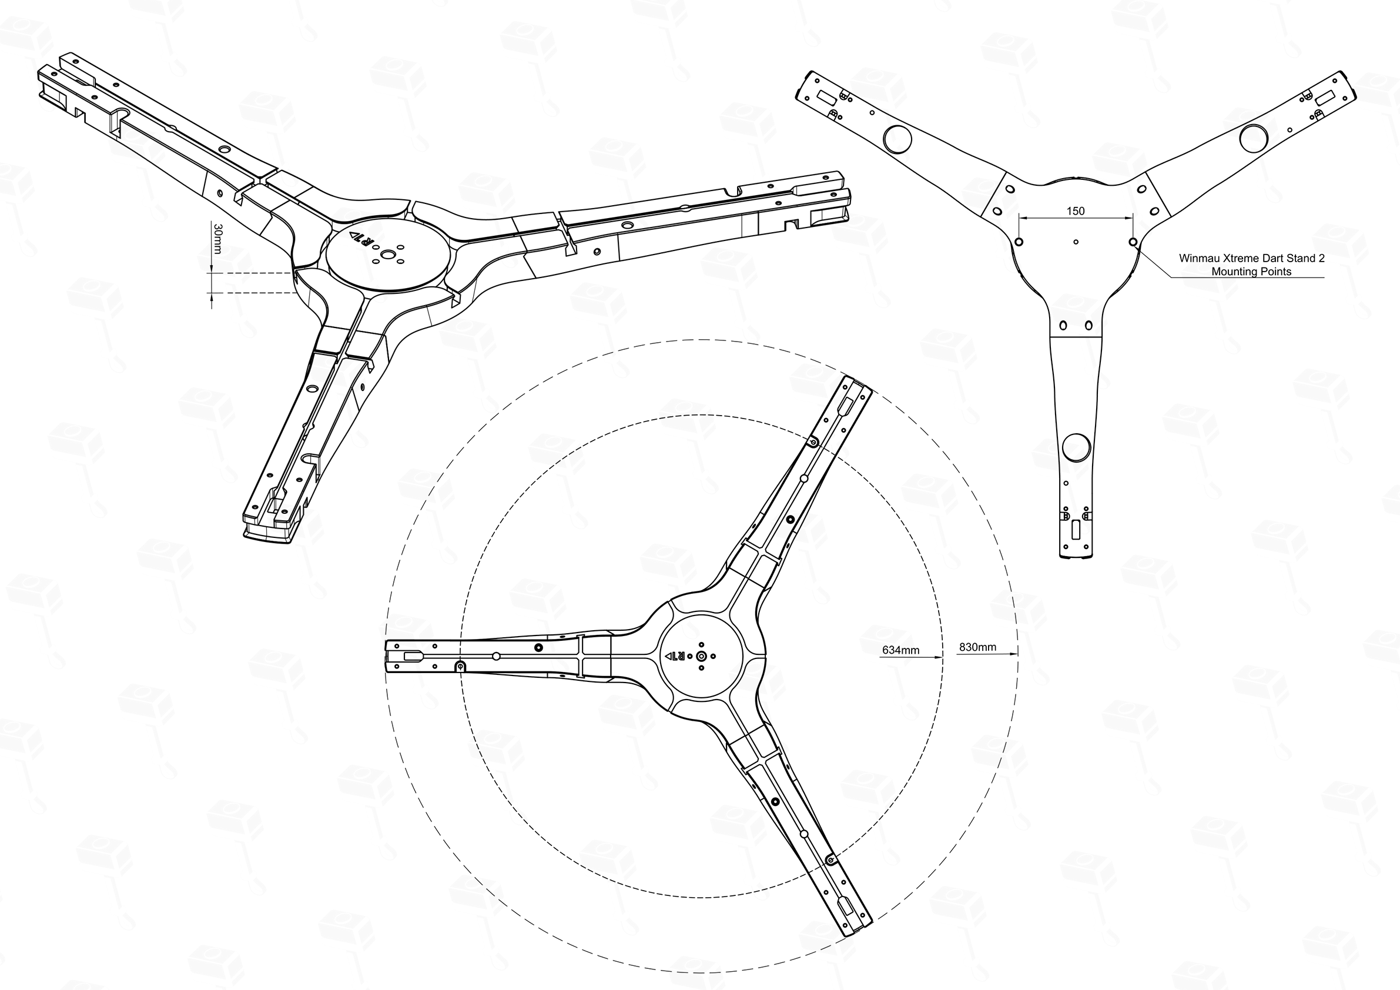
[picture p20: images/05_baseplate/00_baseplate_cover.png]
baseplate_cover


> 📥 **Download Files:** [IT2 Baseplate on Makerworld](https://makerworld.com/en/models/2782096)

---
## Table of Contents
1. [General Overview: The IT2 Baseplate](#1-general-overview-the-it2-baseplate)
2. [What You'll Need](#2-what-youll-need)
3. [General Assembly: Baseplate & System](#3-general-assembly-baseplate--system)
    * [3.1 Step 1: Installing Heat Inserts](#31-step-1-installing-heat-inserts)
    * [3.2 Step 2: Joining the Segments](#32-step-2-joining-the-segments)
    * [3.3 Step 3: Attaching the IT2 System](#33-step-3-attaching-the-it2-system)
4. [Final Step: Installation & Mounting](#4-final-step-installation--mounting)
    * [4.1 Mounting Instructions: Wall Mounting (Option A)](#41-mounting-instructions-wall-mounting-option-a)
    * [4.2 Mounting Instructions: Dartboard Stand (Option B)](#42-mounting-instructions-dartboard-stand-option-b)
5. [Pro Tips: Advanced Features & Addons](#5-pro-tips-advanced-features--addons)
    * [5.1 Noise Dampening](#51-noise-dampening)
    * [5.2 RGB LED Ring Expansion & Camera Shroud](#52-rgb-ring-expansion--camera-shroud)
    * [5.3 Upcoming Features (Work in Progress)](#53-upcoming-features-work-in-progress)

---

## 1. General Overview: The IT2 Baseplate

While the IT2 system can be mounted directly to the wall, the Baseplate offers several key advantages:
*   **Structural Rigidity:** The 4-part design provides superior stability compared to 7-part alternatives. This increased stiffness minimizes bending and flexing, ensuring your camera arms remain in their exact positions.
*   **Minimal Drilling:** Only 3 holes are required in your wall instead of 6+.
*   **Perfect Alignment:** The baseplate ensures that your camera arms are perfectly centered and leveled relative to the bullseye.
*   **Sound Dampening:** Integrated circular recesses for dedicated TPU dampeners to reduce noise transmission.
*   **Stand Compatibility:** Native compatibility with the **Winmau Xtreme 2** mobile dartboard stand by default and without any modifications.

---

## 2. What You'll Need

The Baseplate is designed to use the same hardware as the rest of the IT2 system to keep things simple.

| Part Name | Type | Wall Qty | Stand Qty | Link | Comment |
| --- | --- | --- | --- | ---- | --- |
| Cylindrical Screws | M4x10mm (ISO4762/DIN912) | 8 | 8 | [Aliexpress](https://s.click.aliexpress.com/e/_c4WUfT79)<br>[Amazon.de](https://amzn.to/49r8kCE) | For baseplate assembly and IT2 mounting. |
| M6 Heat Inserts | M6 (8mm OD) | 3 | 7 | [Aliexpress](https://s.click.aliexpress.com/e/_c3iaYfkD) | **Mandatory** for Rota Locks. |
| M4 Heat Inserts ⚠️ | 6.3mm OD (max 9mm long)  | 8-16 | 8-16 | [Aliexpress](https://s.click.aliexpress.com/e/_c3iaYfkD)<br>[Amazon.de](https://amzn.to/4wZr2uZ) | 6mm OD also fits. ⚠️ **Only for Heat Insert version.** |

> 💡 **Wall Mounting Tip:** For wall installation, we recommend using **3x 4mm wood screws** of sufficient length (typical setup: 6mm wall plugs with 30-40mm screws).

> 🖨️ **3D Printing:** If you are not using the Makerworld .3mf profiles, please refer to the **[Universal Printing Guide](PRINTING.md)** for recommended settings and materials.

---

## 3. General Assembly: Baseplate & System

### 3.1 Step 1: Installing Heat Inserts

> 💡 **Important:** While a "Self-Tapping" version of the baseplate is available, this only applies to the M4 mounting points. The **M6 heat inserts** for the Rota Locks are **always mandatory** for all versions, as these parts are adjusted frequently and require the durability of a metal thread to prevent wear.

If you are using the **Heat Insert version**, melt the M4 inserts into the designated holes at the ends of the three mounting arms. 

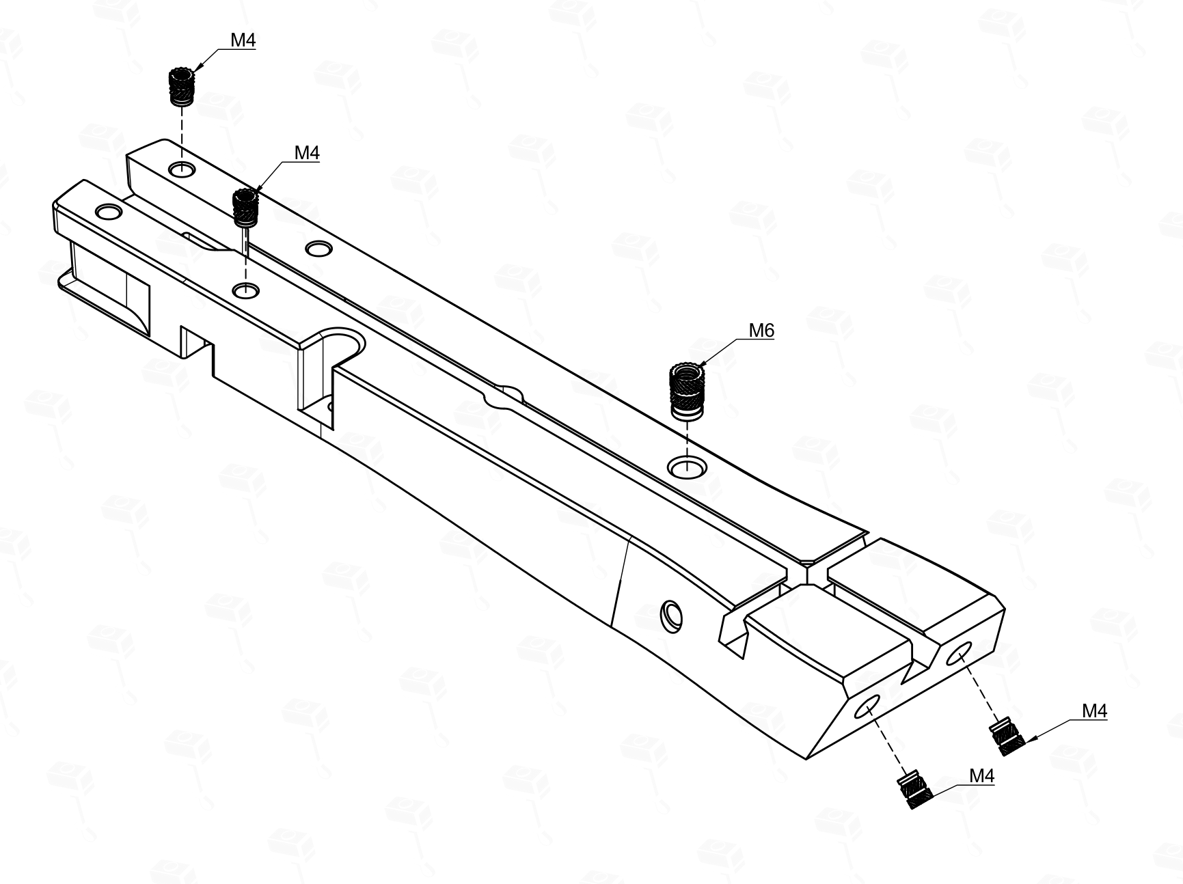
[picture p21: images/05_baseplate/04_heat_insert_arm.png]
heat_insert_arm

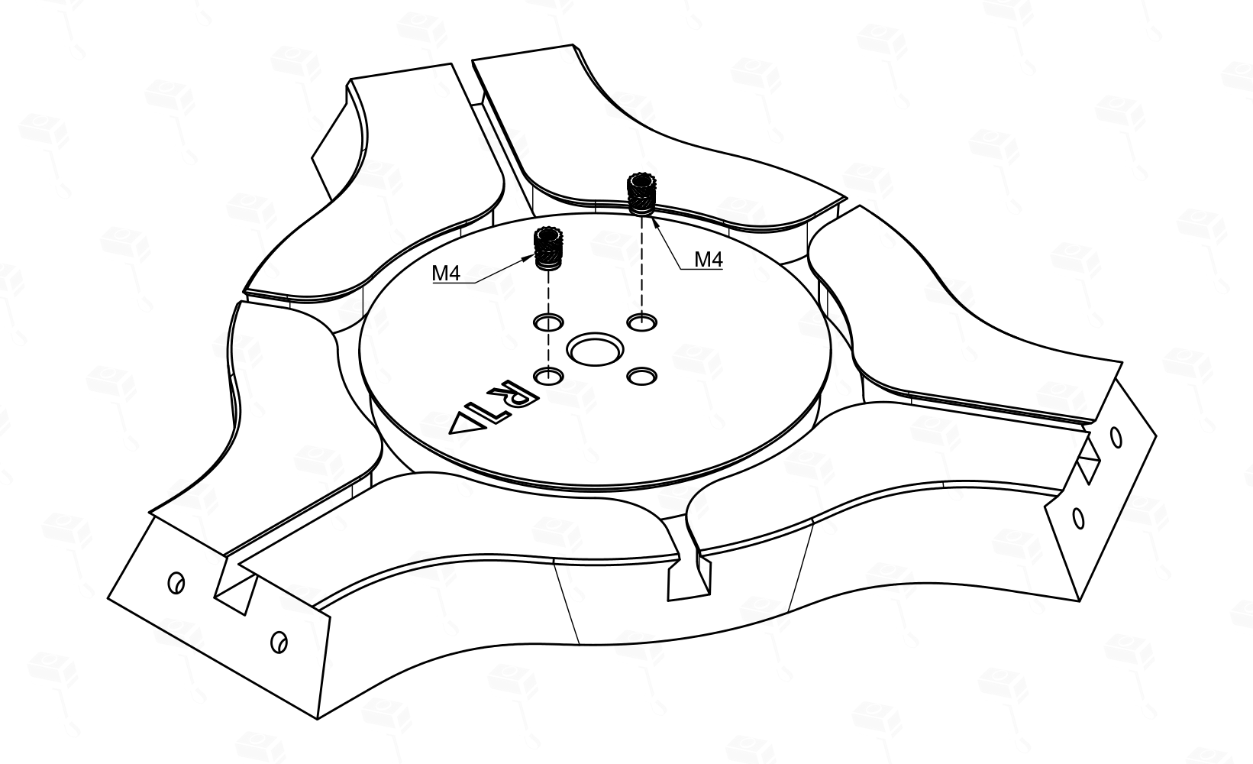
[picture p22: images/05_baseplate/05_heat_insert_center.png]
heat_insert_center


> 💡 **M4 Heat Insert Guide for Dartboard Mounting:**
> Standard Wall Mount: Use **2 inserts as shown in the picture**.
> Portable Stand or Low Ceiling: Use the **other two unused holes** (or all four) per arm.
> Addons: Additional inserts may be required for [Addons](#5-pro-tips-advanced-features--addons).

> 
> ⚠️ **Orientation:** The photos show the **standard alignment**. If you are building for a dart stand or low ceiling, ensure you orient the arms correctly using the alternative mounting holes.

### 3.2 Step 2: Joining the Segments
The three mounting arms are joined to the center point using a simple **face-to-face screw connection**. 
1. Align the mounting arms with the center point.
2. Secure each arm using the provided screw points.

### 3.3 Step 3: Attaching the IT2 System
It is highly recommended to attach your assembled IT2 scoring system to the baseplate before mounting it to the wall or stand. However, you can also perform this step afterwards if preferred.
1.  Place your assembled IT2 system (the three camera arms connected to the ring) onto the baseplate.
2.  Align the legs of the camera arms with the mounting points on the baseplate arms.
3.  Secure the system using **three M4 screws**.

---

## 4. Final Step: Installation & Mounting

The IT2 Baseplate can be mounted either directly to a wall or onto a mobile dartboard stand. Choose the section below that fits your setup.

### 4.1 Mounting Instructions: Wall Mounting (Option A)
Installing the IT2 Baseplate to the wall is simple and precise. 

1.  **Find the Bullseye:** Measure and mark the official bullseye height (**1.73m**) on your wall.
2.  **Positioning:** Align the center hole of the baseplate with your mark. If possible, you can already use a screw for the center point - this allows you to freely rotate the baseplate for perfect alignment.
3.  **Alignment:** Use the "LR" indicators on the arms to position one of the arms in the direction of either the **11 segment** (Left) or the **9 segment** (Right). 
4.  **Leveling:** Finally, use a spirit level on the outer edge to level the baseplate.
5.  **Securing:** Secure the assembly using the remaining wall screws through the holes shown in the image below.

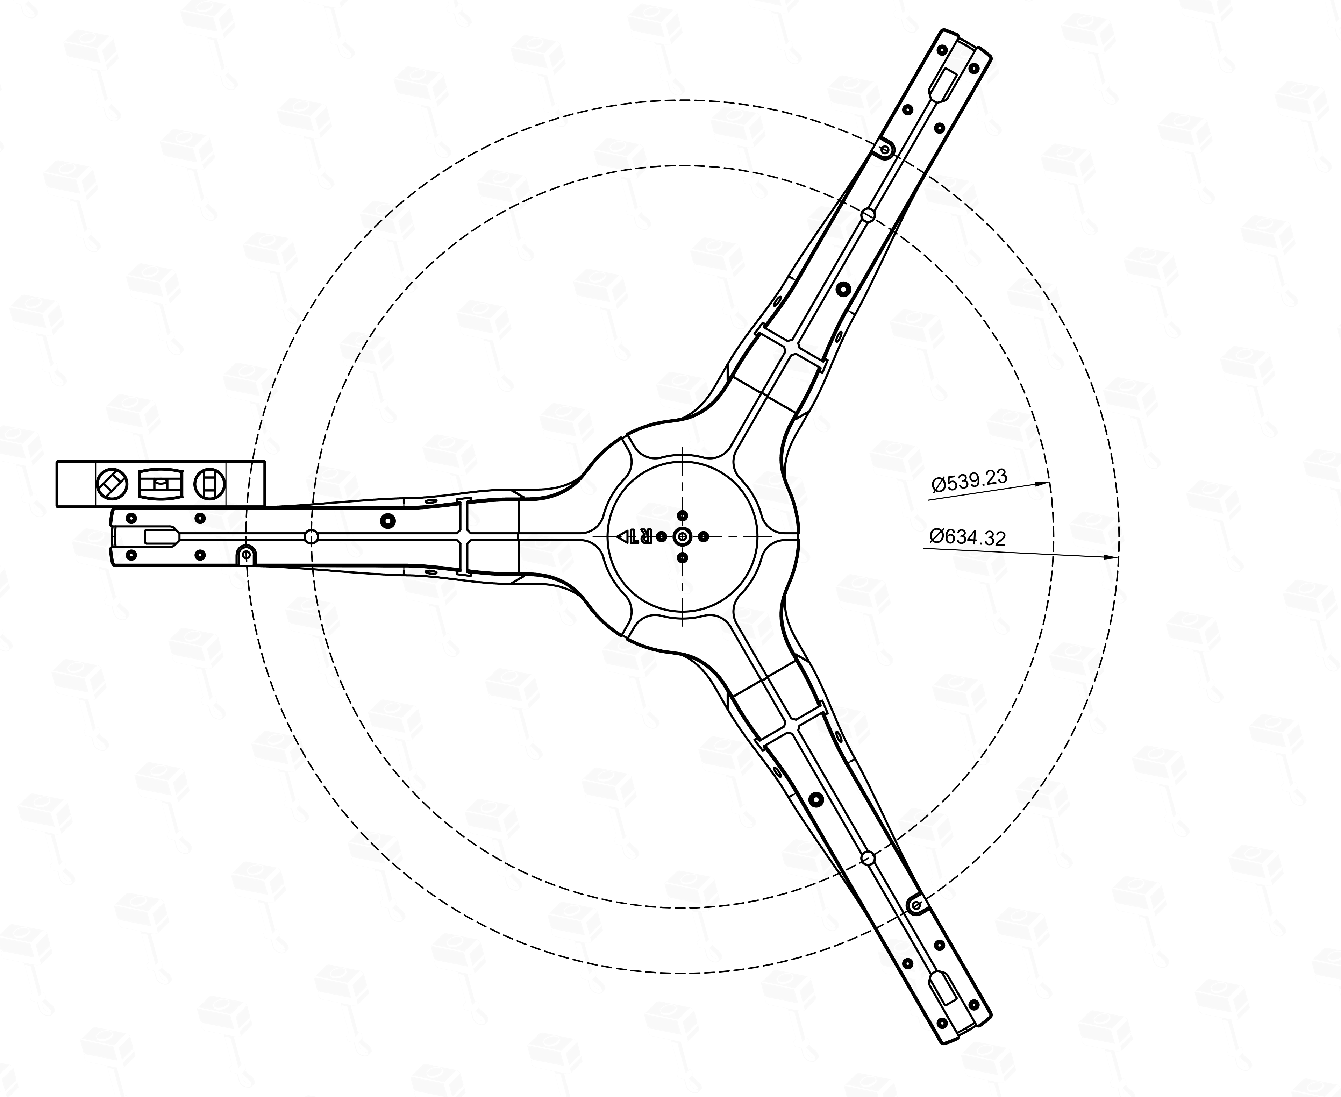
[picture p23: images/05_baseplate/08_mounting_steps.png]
baseplate_mounting_steps


> ⚠️ **Important:** The baseplate adds **30mm of depth** to your setup. You **MUST** move your oche (throw line) back by 30mm to maintain official tournament distances.

### 4.2 Mounting Instructions: Dartboard Stand (Option B)
This method allows for a fully mobile setup. The IT2 Baseplate features a mounting pattern explicitly designed to fit the **Winmau Xtreme Dartboard Stand 2** without modifications.

1.  **Alignment:** Align the baseplate mounting holes with the brackets of your stand.
2.  **Securing:** Use the hardware provided with your stand or M6 screws to secure the baseplate.
3.  **Support (Optional):** If your setup feels top-heavy, we recommend using the additional support addons provided in the print profile (requires 2 extra M6 heat inserts).

---

## 5. Pro Tips: Advanced Features & Addons

The IT2 Baseplate system supports several modular addons to extend its functionality:

### 5.1 Noise Dampening (Optional Addon)
The back of the baseplate segments features **circular threaded recesses** designed for 3D-printed TPU dampeners. These inserts do not make the scoring system quieter for the player, but they effectively prevent vibrations and noise from being transmitted through the wall to other rooms.

#### Installation & Wall Mounting with Dampeners:
If you choose to use the TPU dampeners, the wall mounting process changes:

1.  **Prepare the Baseplate:** Use a screwdriver and a hammer (or a similar tool) to punch out the pre-perforated holes in the center of the baseplate recesses.
2.  **Insert Dampeners:** Screw the 3D-printed TPU dampeners into the threaded recesses.
3.  **Mounting:** Use the holes located in the center of the TPU dampeners to secure the entire assembly to the wall.

> ⚠️ **Important:** Do not over-tighten the screws. The TPU should be held securely but must not be crushed or overly compressed, as this would negate the dampening effect.

### 5.2 RGB LED Ring Expansion & Camera Shroud (Work in Progress)
An upcoming multipurpose expansion designed for both ambient lighting and scoring reliability:
*   **RGB LED Support:** Allows for mounting additional RGB LED strips around the perimeter of the light ring for custom visual effects.
*   **Detection Shroud:** The expansion also acts as a "shroud" or collar that encloses the system. This prevents the cameras from seeing background movements, which significantly improves dart detection.
*   **💡 Recommendation:** This shroud is highly recommended for **portable stand setups**, where a static background cannot always be guaranteed.

### 5.3 Upcoming Features (Work in Progress)
The following features are currently in development:
*   **Integrated Raspberry Pi Mount:** Native support for mounting a Raspberry Pi directly to the baseplate, creating a fully self-contained scoring unit.
*   **Expanded Stand Support:** We are currently evaluating support for additional dartboard stands (e.g., KOTO or budget alternatives) to be released in future updates.

---

[Back to Main Manual](README.md)

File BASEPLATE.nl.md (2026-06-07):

# IT2 Baseplate - Montage- & Installatiehandleiding



> 🛠️ **Hoofdhandleiding:** Op zoek naar de instructies voor het camerasysteem? [Bekijk de IT2 Systeemhandleiding](README.nl.md)
>
> ---
> *Opmerking: Als solo-ontwerper die dit hele project beheert, gebruik ik AI-assistentie om te helpen met de uitgebreide documentatie. Sommige onderdelen kunnen AI-gegenereerde fouten of misverstanden bevatten. Totdat ik de tijd heb om elke sectie volledig te herzien en te verfijnen, verzoeken wij u attent te blijven en contact op te nemen via Discord als u problemen tegenkomt.*

De **IT2 Baseplate** is een montageoplossing voor het IT2 Autodarts-systeem. Het is ontworpen om de installatie te vereenvoudigen, je muren te beschermen en biedt geavanceerde functies zoals geluidsdemping en native compatibiliteit met dartbordstandaards.

baseplate_cover

> 📥 **Bestanden downloaden:** [IT2 Baseplate op Makerworld](https://makerworld.com/en/models/2782096)

---
## Inhoudsopgave
1. [Algemeen Overzicht: De IT2 Baseplate](#1-algemeen-overzicht-de-it2-baseplate)
2. [Wat je nodig hebt](#2-wat-je-nodig-hebt)
3. [Algemene Montage: Baseplate Segmenten](#3-algemene-montage-baseplate-segmenten)
    * [3.1 Stap 1: Heat Inserts installeren](#31-stap-1-heat-inserts-installeren)
    * [3.2 Stap 2: De segmenten verbinden](#32-stap-2-de-segmenten-verbinden)
    * [3.3 Stap 3: Het IT2-systeem bevestigen](#33-stap-3-het-it2-systeem-bevestigen)
4. [Laatste Stap: Installatie & Montage](#4-laatste-stap-installatie--montage)
    * [4.1 Montage-instructies: Wandmontage (Optie A)](#41-montage-instructies-wandmontage-optie-a)
    * [4.2 Montage-instructies: Dartbordstandaard (Option B)](#42-montage-instructies-dartbordstandaard-option-b)
5. [Pro Tips: Geavanceerde Functies & Add-ons](#5-pro-tips-geavanceerde-functies--add-ons)
    * [5.1 Geluidsdemping](#51-geluidsdemping)
    * [5.2 RGB Ring Uitbreiding & Camera Shroud](#52-rgb-ring-uitbreiding--camera-shroud)
    * [5.3 Toekomstige Functies (In ontwikkeling)](#53-toekomstige-functies-in-ontwikkeling)

---

## 1. Algemeen Overzicht: De IT2 Baseplate

Hoewel het IT2-systeem direct aan de muur kan worden gemonteerd, biedt de Baseplate verschillende belangrijke voordelen:
*   **Structurele Stijfheid:** Het 4-delige ontwerp biedt superieure stabiliteit in vergelijking met 7-delige alternatieven. Deze verhoogde stijfheid minimaliseert buigen en doorzakken, waardoor je camera-armen in hun exacte positie blijven.
*   **Minimaal Boren:** Er zijn slechts 3 gaten in je muur nodig in plaats von 6+.
*   **Perfecte Uitlijning:** De baseplate zorgt ervoor dat je camera-armen perfect gecentreerd en waterpas staan ten opzichte van de bullseye.
*   **Geluidsdemping:** Geïntegreerde ronde uitsparingen met schroefdraad voor speciale TPU-dempers om geluidsoverdracht te verminderen.
*   **Compatibiliteit met Standaards:** Native compatibiliteit met de **Winmau Xtreme 2** mobiele dartbordstandaard, standaard en zonder aanpassingen.

---

## 2. What je nodig hebt

De Baseplate is ontworpen om dezelfde hardware te gebruiken als de rest van het IT2-systeem om alles eenvoudig te houden.

| Onderdeel | Type | Wand Qty | Stand Qty | Link | Opmerking |
| --- | --- | --- | --- | ---- | --- |
| Cilinderschroeven | M4x10mm (ISO4762/DIN912) | 8 | 8 | [Aliexpress](https://s.click.aliexpress.com/e/_c4WUfT79)<br>[Amazon.nl](https://amzn.to/49r8kCE) | Voor montage en IT2-bevestiging. |
| M6 Heat Inserts | M6 (8mm OD) | 3 | 7 | [Aliexpress](https://s.click.aliexpress.com/e/_c3iaYfkD) | **Verplicht** voor Rota Locks. |
| M4 Heat Inserts ⚠️ | 6.3mm OD (max 9mm long) | 8-16 | 8-16 | [Aliexpress](https://s.click.aliexpress.com/e/_c3iaYfkD)<br>[Amazon.nl](https://amzn.to/4wZr2uZ) | 6mm OD past ook. ⚠️ **Alleen voor Heat Insert versie.** |

> 💡 **Wandmontage Tip:** Voor wandinstallatie raden we het gebruik van **3x 4mm houtschroeven** aan met voldoende lengte (typische opstelling: 6mm pluggen met 30-40mm schroeven).

> 🖨️ **3D-printen:** Als je de Makerworld .3mf profielen niet gebruikt, raadpleeg dan de **[Universal Printing Guide](PRINTING.md)** voor aanbevolen instellingen en materialen.

---

## 3. Algemene Montage: Baseplate Segmenten

### 3.1 Stap 1: Heat Inserts installeren

> 💡 **Belangrijk:** Hoewel er een "Self-Tapping" versie van de baseplate beschikbaar is, geldt dit alleen voor de M4-bevestigingspunten. De **M6 heat inserts** voor the Rota Locks are **altijd verplicht** voor alle versies, omdat deze onderdelen vaak worden afgesteld en de duurzaamheid van een metalen schroefdraad nodig hebben.

Als je de **Heat Insert versie** gebruikt, smelt dan de M4 inserts in de daarvoor bestemde gaten aan de uiteinden van de drie montagearmen.

heat_insert_arm
heat_insert_center

> 💡 **M4 Heat Insert Gids voor Dartbordmontage:**
> Standaard Wandmontage: Gebruik **2 inserts zoals getoond op de foto**.
> Mobiele Standaard of Laag Plafond: Gebruik de **andere twee ongebruikte gaten** (of alle vier) per arm.
> Add-ons: Extra inserts kunnen nodig zijn voor [Add-ons](#5-pro-tips-geavanceerde-functies--add-ons).

> 
> ⚠️ **Oriëntatie:** De foto's tonen de **standaard uitlijning**. Als je bouwt voor een dartstandaard of laag plafond, zorg er dan voor dat je de armen correct oriënteert (met gebruik van de alternatieve montagegaten).

### 3.2 Stap 2: De segmenten verbinden
De drie montagearmen worden verbonden met het middelpunt via een eenvoudige **face-to-face schroeverbinding**.
1. Lijn de montagearmen uit met het middelpunt.
2. Bevestig elke arm mit de meegeleverde schroefpunten.

### 3.3 Stap 3: Het IT2-systeem bevestigen
Het wordt ten zeerste aanbevolen om je gemonteerde IT2-scoreingssysteem aan de baseplate te bevestigen voordat je deze aan de muur of standaard monteert. Je kunt deze stap echter auch achteraf uitvoeren indien gewenst.
1. Plaats je gemonteerde IT2-systeem (de drie camera-armen verbonden met de ring) op de baseplate.
2. Lijn de poten van de camera-armen uit met de bevestigingspunten op de baseplate-armen.
3. Zet het systeem vast met **drie M4-schroeven**.

---

## 4. Laatste Stap: Installatie & Montage

De IT2 Baseplate kan direct aan een muur of op een mobiele dartbordstandaard worden gemonteerd. Kies de sectie hieronder die past bij jouw opstelling.

### 4.1 Montage-instructies: Wandmontage (Optie A)
Het installeren van de IT2 Baseplate aan de muur is eenvoudig en nauwkeurig.

1.  **Bullseye vinden:** Meet en markeer de officiële bullseye-hoogte (**1,73 m**) op je muur.
2.  **Positionering:** Lijn het middelste gat van de baseplate uit met de gemarkeerde bullseye-hoogte. Indien mogelijk kun je het middelpunt alvast met een schroef vastzetten - hierdoor kun je de baseplate vrij draaien voor een perfecte uitlijning.
3.  **Uitlijning:** Gebruik de „LR“-indicatoren op de armen om een van de armen in de richting van het **11-segment** (Links) of het **9-segment** (Rechts) te positioneren.
4.  **Waterpas zetten:** Gebruik tot slot een waterpas op de buitenrand om de baseplate waterpas te stellen.
5.  **Vastzetten:** Schroef de baseplate aan de muur op de plaatsen die in de onderstaande afbeelding worden getoond.

baseplate_mounting_steps

> ⚠️ **Belangrijk:** De baseplate voegt **30mm diepte** toe aan je opstelling. Je **MOET** je oche (werplijn) met 30mm naar achteren verplaatsen om de officiële toernooiafstanden te behouden.

### 4.2 Montage-instructies: Dartbordstandaard (Option B)
Deze methode maakt een volledig mobiele opstelling mogelijk. De IT2 Baseplate heeft een gatenpatroon dat expliciet is ontworpen om zonder aanpassingen op de **Winmau Xtreme Dartboard Stand 2** te passen.

1.  **Uitlijning:** Lijn de montagegaten van de baseplate uit met de beugels van je standaard.
2.  **Vastzetten:** Gebruik de hardware die bij je standaard is geleverd of M6-schroeven om de baseplate vast te zetten.
3.  **Ondersteuning (Optioneel):** Als je opstelling topzwaar aanvoelt, raden we aan de extra ondersteunings-add-ons te gebruiken die in het printprofiel zijn meegeleverd (vereist 2 extra M6 heat inserts).

---

## 5. Pro Tips: Geavanceerde Functies & Add-ons

Het IT2 Baseplate-systeem ondersteunt verschillende modulaire add-ons om de functionaliteit uit te breiden:

### 5.1 Geluidsdemping (Optionele Add-on)
De achterkant van de baseplate-segmenten is voorzien van **ronde uitsparingen met schroefdraad** ontworpen voor 3D-geprinte TPU-dempers. Deze inserts maken het scoreingssysteem niet stiller voor de speler, maar ze voorkomen effectief dat trillingen en geluid via de muur naar andere kamers worden overgedragen.

#### Installatie & Wandmontage met dempers:
Als je ervoor kiest om de TPU-dempers te gebruiken, verandert het proces van wandmontage:

1.  **Baseplate voorbereiden:** Gebruik een schroevendraaier en een hamer (of vergelijkbaar gereedschap) om de voorgeperforeerde gaten in het midden van de baseplate-uitsparingen eruit te slaan.
2.  **Dempers plaatsen:** Schroef de 3D-geprinte TPU-dempers in de uitsparingen met schroefdraad.
3.  **Montage:** Gebruik de gaten in het midden van de TPU-dempers om het geheel aan de muur te bevestigen.

> ⚠️ **Belangrijk:** Draai de schroeven niet te vast aan. Het TPU moet stevig vastzitten, maar mag niet geplet of overmatig samengedrukt worden, omdat dit het dempende effect teniet zou doen.

### 5.2 RGB Ring Uitbreiding & Camera Shroud (In ontwikkeling)
Een aankomende multifunctionele uitbreiding ontworpen voor zowel sfeerverlichting als betrouwbaarheid van de scoreherkenning:
*   **RGB LED Ondersteuning:** Maakt het mogelijk om extra RGB LED-strips rond de buitenkant van de lichtring te monteren voor eigen visuele effecten.
*   **Detectie Shroud:** De uitbreiding fungeert ook als een "shroud" of kraag die het systeem omsluit. Dit voorkomt dat de camera's achtergrondbewegingen zien, wat de detectie van de darts aanzienlijk verbetert.
*   **💡 Aanbeveling:** Deze shroud wordt ten zeerste aanbevolen voor **mobiele standaard-opstellingen**, waar een statische achtergrond niet altijd gegarandeerd kan worden.

### 5.3 Toekomstige Functies (In ontwikkeling)
De volgende functies zijn momenteel in ontwikkeling:
*   **Geïntegreerde Raspberry Pi houder:** Native ondersteuning voor het direct monteren van een Raspberry Pi op de baseplate voor een volledig zelfstandige score-eenheid.
*   **Uitgebreide ondersteuning voor standaards:** We evalueren momenteel de ondersteuning voor extra dartbordstandaards (bijv. KOTO of budgetalternatieven) voor toekomstige updates.

---

[Terug naar de hoofdhandleiding](README.nl.md)

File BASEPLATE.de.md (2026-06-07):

# IT2 Baseplate - Montage- & Installationsanleitung



> 🛠️ **Hauptanleitung:** Suchst du die Anleitung für das Kamerasystem? [Hier geht es zum IT2 System Manual](README.de.md)
>
> ---
> *Hinweis: Da ich dieses Projekt als Einzel-Designer leite, nutze ich KI-Unterstützung für die umfangreiche Dokumentation. Es kann sein, dass manche Abschnitte aufgrund von KI-Fehlern unklar sind. Bis ich Zeit für eine vollständige Prüfung habe, seid bitte aufmerksam und meldet Unklarheiten direkt im Discord.*

Die **IT2 Baseplate** ist eine Montagelösung für das IT2 Autodarts-System. Sie wurde entwickelt, um die Installation zu vereinfachen, die Wände zu schützen und bietet erweiterte Funktionen wie Schalldämmung und native Kompatibilität mit Dartboard-Ständern.

baseplate_cover

> 📥 **Dateien herunterladen:** [IT2 Baseplate auf Makerworld](https://makerworld.com/en/models/2782096)

---
## Inhaltsverzeichnis
1. [Allgemeine Übersicht: Die IT2 Baseplate](#1-allgemeine-ubersicht-die-it2-baseplate)
2. [Was du benötigst](#2-was-du-benotigst)
3. [Allgemeine Montage: Baseplate-Segmente](#3-allgemeine-montage-baseplate-segmente)
    * [3.1 Schritt 1: Installation der Schmelzeinsätze](#31-schritt-1-installation-der-schmelzeinsatze)
    * [3.2 Schritt 2: Verbinden der Segmente](#32-schritt-2-verbinden-der-segmente)
    * [3.3 Schritt 3: Befestigen des IT2-Systems](#33-schritt-3-befestigen-des-it2-systems)
4. [Letzter Schritt: Installation & Montage](#4-letzter-schritt-installation--montage)
    * [4.1 Montageanleitung: Wandmontage (Option A)](#41-montageanleitung-wandmontage-option-a)
    * [4.2 Montageanleitung: Dartboard-Ständer (Option B)](#42-montageanleitung-dartboard-stander-option-b)
5. [Pro-Tipps: Erweiterte Funktionen & Addons](#5-pro-tipps-erweiterte-funktionen--addons)
    * [5.1 Schalldämmung](#51-schalldammung)
    * [5.2 RGB-Ring-Erweiterung & Kamera-Blende](#52-rgb-ring-erweiterung--kamera-blende)
    * [5.3 Kommende Funktionen (In Arbeit)](#53-kommende-funktionen-in-arbeit)

---

## 1. Allgemeine Übersicht: Die IT2 Baseplate

Obwohl das IT2-System direkt an der Wand montiert werden kann, bietet die Baseplate mehrere entscheidende Vorteile:
*   **Strukturelle Steifigkeit:** Das 4-teilige Design bietet im Vergleich zu 7-teiligen Alternativen eine überlegene Stabilität. Diese erhöhte Steifigkeit minimiert das Verbiegen und stellt sicher, dass deine Kameraarme in ihrer exakten Position bleiben.
*   **Minimales Bohren:** Es werden nur 3 Löcher in der Wand benötigt statt 6 oder mehr.
*   **Perfekte Ausrichtung:** Die Baseplate stellt sicher, dass deine Kameraarme perfekt zentriert und nivelliert zum Bullseye ausgerichtet sind.
*   **Schalldämmung:** Integrierte kreisförmige Gewinde-Aussparungen für spezielle TPU-Dämpfer zur Reduzierung der Schallübertragung.
*   **Ständer-Kompatibilität:** Native Kompatibilität mit dem **Winmau Xtreme 2** Dartboard-Ständer, standardmäßig und ohne Modifikationen.

---

## 2. Was du benötigst

Die Baseplate nutzt die gleiche Hardware wie das restliche IT2-System, um alles einfach zu halten.

| Name | Typ | Wand Qty | Ständer Qty | Link | Kommentar |
| --- | --- | --- | --- | ---- | --- |
| Zylinderschrauben | M4x10mm (ISO4762/DIN912) | 8 | 8 | [Aliexpress](https://s.click.aliexpress.com/e/_c4WUfT79)<br>[Amazon.de](https://amzn.to/49r8kCE) | Für Montage und IT2-Befestigung. |
| M6 Schmelzeinsätze | M6 (8mm OD) | 3 | 7 | [Aliexpress](https://s.click.aliexpress.com/e/_c3iaYfkD) | **Pflicht** für Rota Locks. |
| M4 Schmelzeinsätze ⚠️ | 6.3mm OD (max 9mm lang) | 8-16 | 8-16 | [Aliexpress](https://s.click.aliexpress.com/e/_c3iaYfkD)<br>[Amazon.de](https://amzn.to/4wZr2uZ) | 6mm OD passt auch. ⚠️ **Nur für Schmelzeinsatz-Version.** |

> 💡 **Tipp zur Wandmontage:** Für die Wandinstallation empfehlen wir **3x 4mm Holzschrauben** in ausreichender Länge (typisches Setup: 6mm Dübel mit 30-40mm Schrauben).

> 🖨️ **3D-Druck:** Wenn du nicht die Makerworld .3mf-Profile nutzt, schau dir bitte den **[Universal Printing Guide](PRINTING.md)** für empfohlene Einstellungen und Materialien an.

---

## 3. Allgemeine Montage: Baseplate-Segmente

### 3.1 Schritt 1: Installation der Schmelzeinsätze

> 💡 **Wichtig:** Obwohl eine "Self-Tapping"-Version der Baseplate verfügbar ist, gilt dies nur für die M4-Befestigungspunkte. Die **M6 Schmelzeinsätze** für die Rota Locks sind für alle Versionen **immer Pflicht**, da diese Teile häufig justiert werden und die Haltbarkeit eines Metallgewindes benötigen.

Wenn du die **Schmelzeinsatz-Version** nutzt, schmelze die M4-Einsätze in die vorgesehenen Löcher an den Enden der drei Montagearme ein.

heat_insert_arm
heat_insert_center

> 💡 **M4 Schmelzeinsatz-Guide für Dartboard-Montage:**
> Standard-Wandmontage: Nutze **2 Einsätze wie auf dem Foto gezeigt**.
> Mobiler Ständer oder niedrige Decke: Nutze die **anderen zwei ungenutzten Löcher** (oder alle vier) pro Arm.
> Addons: Zusätzliche Einsätze können für [Addons](#5-pro-tipps-erweiterte-funktionen--addons) erforderlich sein.

> 
> ⚠️ **Ausrichtung:** Die Fotos zeigen die **Standard-Ausrichtung**. Wenn du für einen Dartständer oder eine niedrige Decke baust, stelle sicher, dass du die Arme korrekt ausrichtest (unter Nutzung der alternativen Befestigungslöcher).

### 3.2 Schritt 2: Verbinden der Segmente
Die drei Montagearme werden über eine einfache **Face-to-Face Schraubverbindung** mit dem Mittelstück verbunden.
1. Richte die Montagearme am Mittelstück aus.
2. Befestige jeden Arm an den vorgesehenen Schraubpunkten.

### 3.3 Schritt 3: Befestigen des IT2-Systems
Es wird dringend empfohlen, dein fertig montiertes IT2-System an der Baseplate zu befestigen, bevor du diese an der Wand oder dem Ständer montierst. Du kannst diesen Schritt jedoch auch später durchführen.
1. Platziere dein IT2-System (die drei mit dem Ring verbundenen Kameraarme) auf der Baseplate.
2. Richte die Beine der Kameraarme an den Befestigungspunkten der Baseplate-Arme aus.
3. Befestige das System mit **drei M4-Schrauben**.

---

## 4. Letzter Schritt: Installation & Montage

Die IT2 Baseplate kann entweder direkt an einer Wand oder an einem mobilen Dartboard-Ständer montiert werden. Wähle den Abschnitt, der zu deinem Setup passt.

### 4.1 Montageanleitung: Wandmontage (Option A)
Die Montage der IT2 Baseplate an der Wand ist einfach und präzise.

1.  **Bullseye finden:** Miss und markiere die offizielle Bullseye-Höhe (**1,73 m**) an deiner Wand.
2.  **Positionierung:** Richte das Mittelloch der Baseplate an deiner Markierung aus. Falls möglich, kannst du den Mittelpunkt direkt mit einer Schraube befestigen - so lässt sich die Baseplate für eine perfekte Ausrichtung frei drehen.
3.  **Ausrichtung:** Nutze die „LR“-Markierungen an den Armen, um einen der Arme entweder in Richtung des **11er-Segments** (Links) oder des **9er-Segments** (Rechts) zu positionieren.
4.  **Nivellierung:** Verwende abschließend eine Wasserwaage an der Außenkante, um die Baseplate exakt zu nivellieren.
5.  **Befestigung:** Schraube die Baseplate an den im Bild unten gezeigten Stellen an der Wand fest.

baseplate_mounting_steps

> ⚠️ **Wichtig:** Die Baseplate fügt deinem Setup **30mm Tiefe** hinzu. Du **MUSST** dein Oche (Abwurflinie) um 30mm nach hinten verschieben, um die offiziellen Turnierspiel-Distanzen einzuhalten.

### 4.2 Montageanleitung: Dartboard-Ständer (Option B)
Diese Methode ermöglicht ein voll mobiles Setup. Die IT2 Baseplate verfügt über ein Lochmuster, das explizit und ohne Modifikationen auf den **Winmau Xtreme Dartboard Stand 2** passt.

1.  **Ausrichtung:** Richte die Montagelöcher der Baseplate an den Halterungen deines Ständers aus.
2.  **Befestigung:** Nutze die mit deinem Ständer gelieferte Hardware oder M6-Schrauben, um die Baseplate zu fixieren.
3.  **Stütze (Optional):** Wenn sich dein Setup kopflastig anfühlt, empfehlen wir die Nutzung der zusätzlichen Stütz-Addons aus dem Druckprofil (erfordert 2 zusätzliche M6 Schmelzeinsätze).

---

## 5. Pro-Tipps: Erweiterte Funktionen & Addons

Das IT2 Baseplate-System unterstützt mehrere modulare Addons zur Funktionserweiterung:

### 5.1 Schalldämmung (Optionales Addon)
Die Rückseite der Baseplate-Segmente verfügt über **kreisförmige Gewinde-Aussparungen** für 3D-gedruckte TPU-Dämpfer. Diese Einsätze machen das System für den Spieler nicht leiser, aber sie verhindern effektiv, dass Vibrationen und Geräusche durch die Wand in andere Räume übertragen werden.

#### Installation & Wandmontage mit Dämpfern:
Wenn du dich für die Nutzung der TPU-Dämpfer entscheidest, ändert sich der Vorgang der Wandmontage:

1.  **Vorbereitung der Baseplate:** Nutze einen Schraubendreher und einen Hammer (oder ein ähnliches Werkzeug), um die vorperforierten Sollbruchstellen in der Mitte der Aussparungen herauszuschlagen.
2.  **Dämpfer einsetzen:** Schraube die 3D-gedruckten TPU-Dämpfer in die Gewinde-Aussparungen.
3.  **Montage:** Nutze die Löcher in der Mitte der TPU-Dämpfer, um die gesamte Einheit an der Wand zu befestigen.

> ⚠️ **Wichtig:** Ziehe die Schrauben nicht zu fest an. Das TPU sollte sicher gehalten, aber nicht gequetscht oder übermäßig komprimiert werden, da dies den Dämpfungseffekt aufheben würde.

### 5.2 RGB-Ring-Erweiterung & Kamera-Blende (In Arbeit)
Eine kommende Mehrzweck-Erweiterung für Ambiente-Beleuchtung und Erkennungszuverlässigkeit:
*   **RGB-LED-Support:** Ermöglicht die Montage zusätzlicher RGB-LED-Streifen um den Außenrand des Lichtrings für eigene visuelle Effekte.
*   **Erkennungs-Blende (Shroud):** Die Erweiterung fungiert auch als Blende, die das System umschließt. Dies verhindert, dass die Kameras Hintergrundbewegungen erfassen, was die Pfeilerkennung erheblich verbessert.
*   **💡 Empfehlung:** Diese Blende wird dringend für **mobile Ständer-Setups** empfohlen, bei denen ein statische Hintergrund nicht immer garantiert werden kann.

### 5.3 Kommende Funktionen (In Arbeit)
Folgende Funktionen befinden sich derzeit in der Entwicklung:
*   **Integrierte Raspberry Pi Halterung:** Native Unterstützung zur Montage eines Raspberry Pi direkt an der Baseplate für eine vollkommen autarke Scoring-Einheit.
*   **Erweiterte Ständer-Unterstützung:** Wir prüfen derzeit die Unterstützung für weitere Dartständer (z.B. KOTO oder Budget-Alternativen) für zukünftige Updates.

---

[Zurück zur Hauptanleitung](README.de.md)

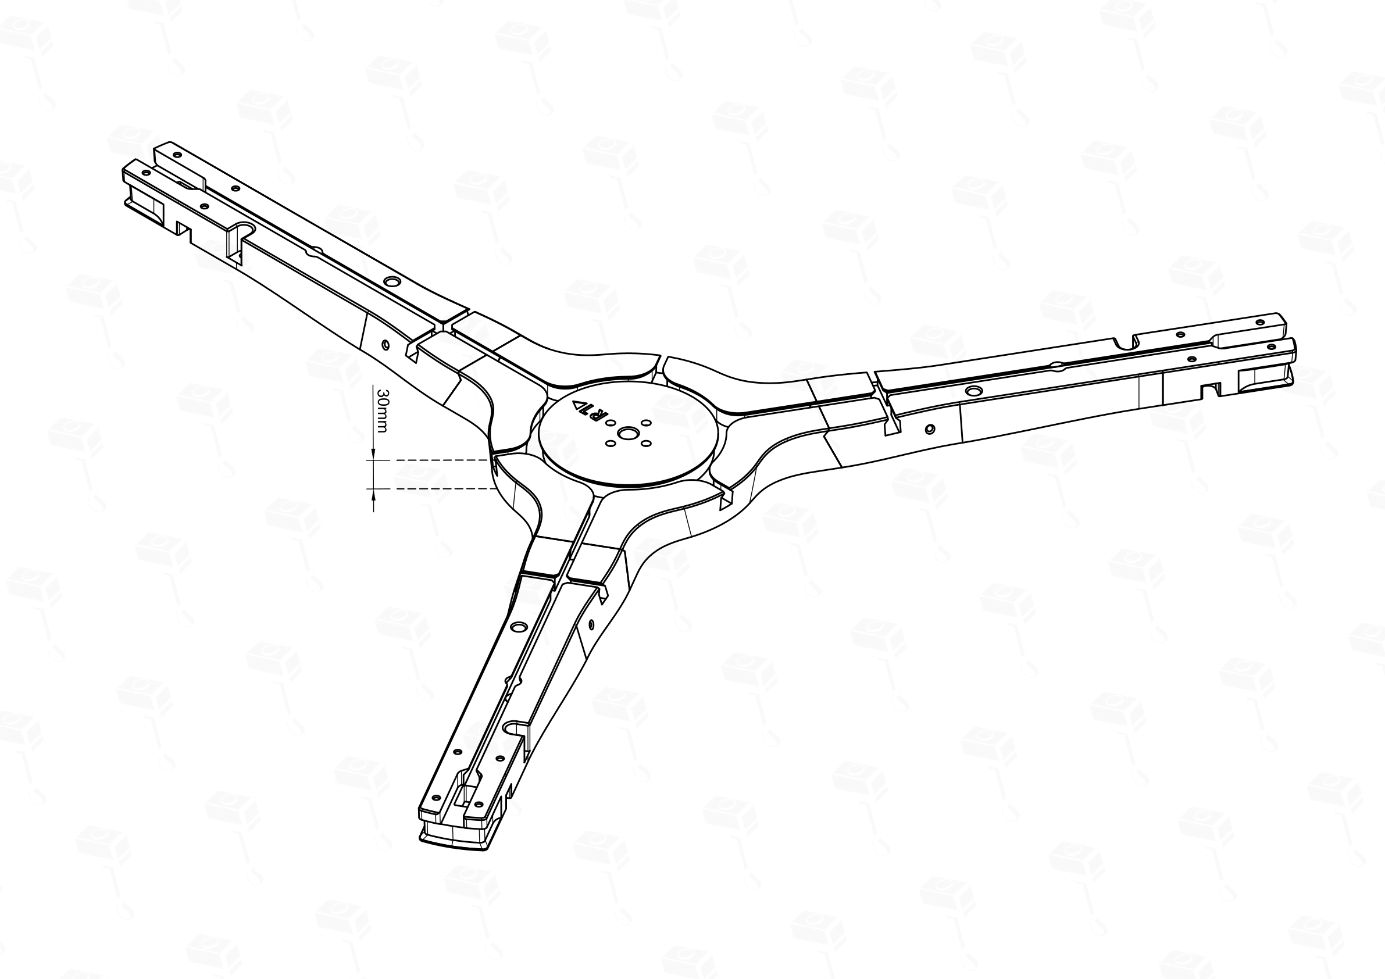
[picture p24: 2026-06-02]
images/05_baseplate/02_front_diagonal.png

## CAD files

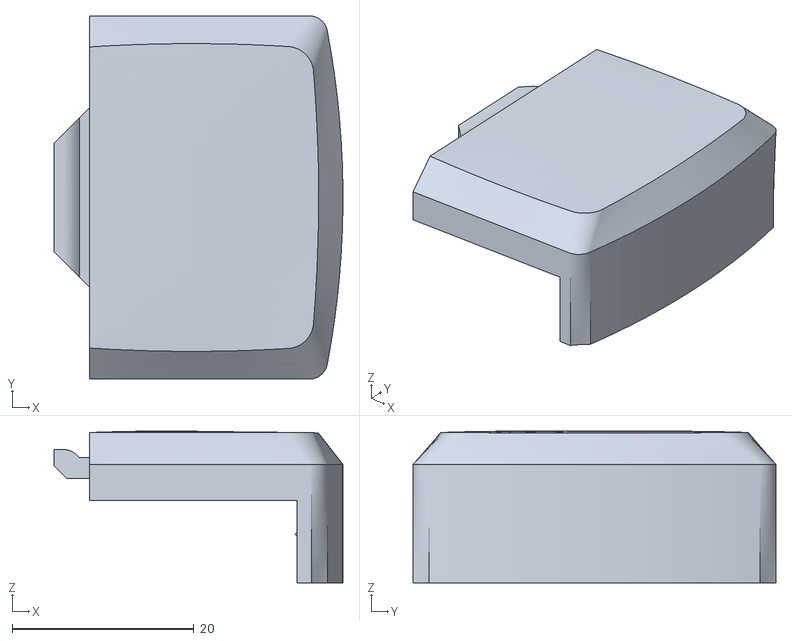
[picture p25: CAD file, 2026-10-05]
Alternative Files/closed screw lid.stl
31.8 x 40.0 x 16.7

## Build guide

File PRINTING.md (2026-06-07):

# IT2 System - Universal Printing Guide

This guide provides the recommended 3D printing settings and orientations for all components of the IT2 Autodarts system. 

> 💡 **Using Makerworld .3mf files?** If you are using the official print profiles on Makerworld, these settings and orientations are already pre-configured. You can skip this guide and proceed directly to assembly.
>
> ---
> *Note: Since I'm managing this project on my own, I use AI to help with the repetitive parts of the documentation - mostly for managing hyperlinks and fine-tuning the wording. I'm currently focused on getting all the technical content out there so you can start building as soon as possible. I'll be doing a full proofread and "ironing out" the phrasing later, but if you spot anything confusing in the meantime, please let me know on Discord!*

---

## Table of Contents
1. [Material Recommendations](#1-material-recommendations)
2. [General Settings (All Parts)](#2-general-settings-all-parts)
3. [Printing Orientation (STL Users)](#3-printing-orientation-stl-users)
4. [Component Specifics](#4-component-specifics)
    * [4.1 Main Components (Arms, Ring & Baseplate)](#41-main-components-arms-ring--baseplate)
    * [4.2 Baseplate Sound Dampeners (TPU)](#42-baseplate-sound-dampeners-tpu)

---

## 1. Material Recommendations

Choosing the right material depends on your environment and your printer setup.

| Environment | Material | Comment |
| --- | --- | --- |
| **Indoor** | PLA | Sufficient for most setups |
| **Outdoor** | PETG / ASA | Better UV and temperature resistance |
| **High-Temp** | **PLA HT** | Alternative if your printer is open-frame |
| **Dampeners** | **TPU 95A** | Mandatory for sound insulation functionality|

> 💡 **Printer Tip:** PETG and especially ASA print best in **enclosed printers**. If you are using an **open-frame printer** (like the Bambu Lab A1), printing large ASA parts can be challenging due to warping. In this case, consider using **PLA HT (High Temperature)** for better thermal stability without the need for an enclosure.

---

## 2. General Settings (All Parts)

Unless specified otherwise, use these settings for a perfect balance of strength and printability:

| Setting | Recommendation | Reason |
| --- | --- | --- |
| **Layer Height**| **0.2mm** | Mandatory for correct bridging & tolerances |
| **Wall Loops**  | 2 - 3 | Provides structural rigidity |
| **Infill** | 10% - 25% | **Cross Hatch** or **Gyroid** recommended |
| **Supports** | **Disabled** | All parts are designed support-free |

---

## 3. Printing Orientation (STL Users)

If you are importing STLs into your slicer, ensure you follow the orientations shown below for optimal strength and support-free results:

### 3.1 IT2 System (Arms & Ring)
it2_orientation

### 3.2 IT2 Baseplate
baseplate_orientation

### 3.3 TPU Sound Dampeners
tpu_orientation

---

## 4. Component Specifics

### 4.1 Main Components (Arms, Ring & Baseplate)
These parts utilize the standard settings defined in Section 2.

*   **Makerworld (Main System):** [Official IT2 System Profile](https://makerworld.com/en/models/1334165)
*   **Makerworld (Baseplate):** [Official IT2 Baseplate Profile](https://makerworld.com/en/models/2782096)

> 📝 **Technical Note:** Ensure your filament is calibrated. Tight tolerances on dovetail joints require a clean print, and the 4-part baseplate design relies on the **0.2mm layer height** for optimal bridging performance.

> ⚠️ **Baseplate Hardware Tip:** If you are printing the **Self-Tapping** version of the baseplate, please note that this only applies to the M4 screws. The **M6 heat inserts** for the Rota Locks are **always mandatory** for all versions, as these components are adjusted frequently and require metal threads for long-term reliability.

### 4.2 Baseplate Sound Dampeners (TPU)
*   **Material:** TPU 95A.
*   **Infill:** 6%.
*   **Infill Type:** 3D Honeycomb.
*   **Wall Loops:** 1 or max 2.

> 📝 **Pro Tip:** Use "Print sequence: By object" to minimize stringing.

---

[Back to Main Manual](README.md) | [Back to Baseplate Manual](BASEPLATE.md)

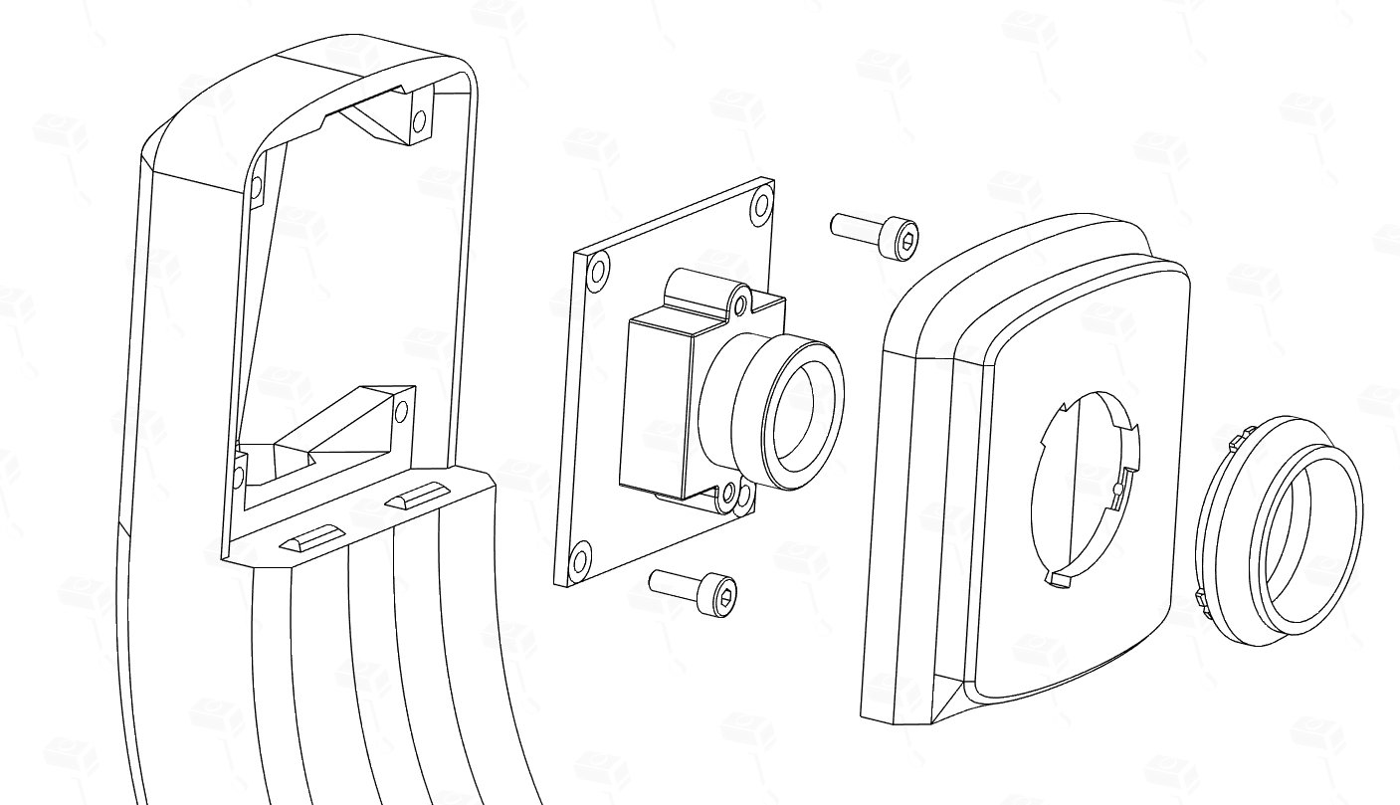
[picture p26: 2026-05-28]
images/head-assembly.png

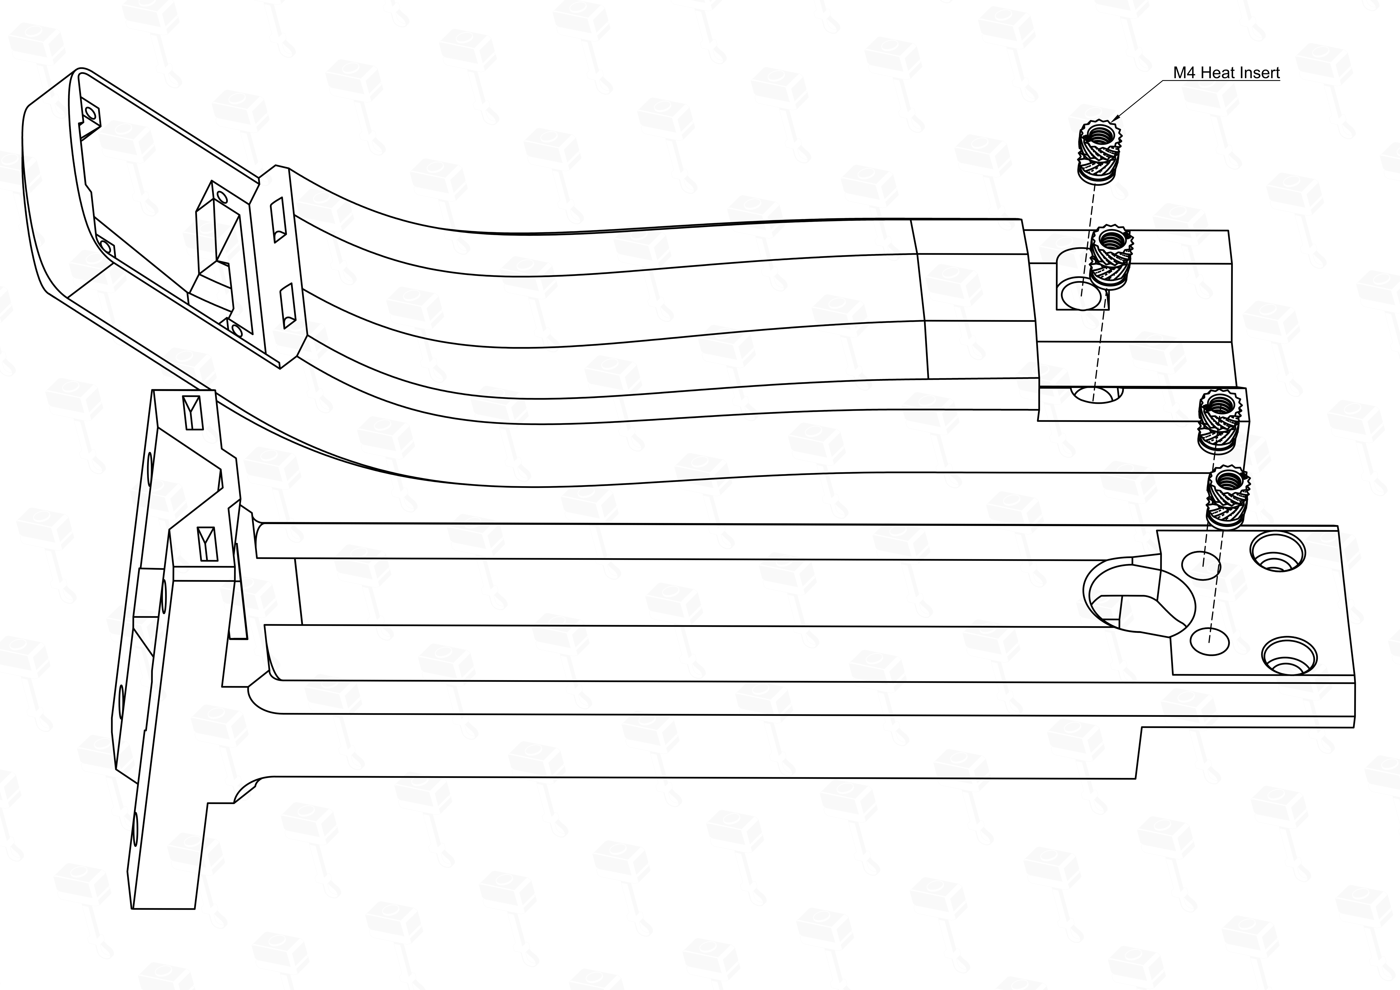
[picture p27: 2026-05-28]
images/head-to-arm-assembly.png

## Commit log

2026-05-28 Added German translation and language switcher
2026-05-28 Added camera pliers illustration to manual
2026-05-29 Restructure manual: consolidate assembly steps, update images, and synchronize DE/EN versions
2026-05-29 Simplify screw terminology in instructions: remove lengths, keep only M4/M2 references
2026-05-29 Generalize LED strip terminology: removed specific brand/temp mentions in instructions and electronics table
2026-05-29 Restore Auxmer brand in electronics table while keeping assembly instructions general
2026-05-29 Final cleanup: remove duplicate licensing/support sections and generalize LED strip mentions in instructions
2026-05-29 Add Discord and Buy Me a Coffee buttons to top of manuals
2026-05-30 Update documentation: New features, detailed assembly steps for Winmau/Target, and FAQ section
2026-05-30 Add Dutch translation and update language switchers
2026-05-31 docs: add aliexpress hyperlinks to cylindrical screws in BOM
2026-05-31 docs: add amazon hyperlink to M4 screws in BOM
2026-05-31 docs: add amazon hyperlink to M2 screws in BOM
2026-05-31 docs: rename Amazon to Amazon.de in BOM tables
2026-05-31 docs: add amazon.de link for M4 heat inserts in BOM
2026-05-31 docs: specify max length for M4 heat inserts in BOM
2026-05-31 docs: add aliexpress hyperlink for M4 heat inserts in BOM
2026-05-31 docs: remove redundant cable management and alignment info
2026-05-31 docs: clarify slimmest 3D-printed design claim
2026-05-31 docs: refine M2 screw terminology and quantity in key features
2026-05-31 docs: copy detailed assembly steps from 4.2 to 4.4 in all languages
2026-05-31 docs: clarify drilling requirements for direct mounting
2026-05-31 docs: add Link column to tools table and Amazon.de link for Hex Key Set
2026-05-31 docs: add Amazon.de link for pliers in tools table
2026-05-31 docs: add Amazon.de link for soldering iron in tools table
2026-05-31 docs: add Aliexpress link for soldering iron in tools table
2026-05-31 docs: implement Low Ceiling assembly image in all languages
2026-05-31 docs: add assembly tip for Low Ceiling version layout
2026-05-31 docs: update Low Ceiling assembly image with correction
2026-05-31 docs: add placeholders for mounting instructions 5.1 and 5.2 in README.md
2026-05-31 docs: remove technical explanation about PCB bending in tips section
2026-05-31 docs: refine screw tightening guidance and add caution for self-tapping
2026-05-31 docs: refine over-tightening warning to specify heat inserts
2026-05-31 docs: add Aliexpress link for HBV OV2710 cameras in recommended electronics
2026-05-31 docs: add Aliexpress link for Auxmer LED strip in recommended electronics
2026-05-31 docs: add power supply and dc barrel connector to recommended electronics
2026-06-02 Comprehensive documentation update: Added BASEPLATE.md, PRINTING.md, and synchronized manuals with new structure, warnings, and AI disclosure.
2026-06-06 docs: final polish, restructured mounting sections, and synchronized translations
2026-10-05 Add image to README for Closed Screw Lid
